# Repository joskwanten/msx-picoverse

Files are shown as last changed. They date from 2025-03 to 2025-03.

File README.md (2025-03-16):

# MSX PicoVerse - The MSX experience driven by the RaspBerry Pi Pico

The MSX PicoVerse is an open-source initiative aimed at developing multi-function cartridges for the MSX line of computers, utilizing variations of the Raspberry Pi Pico development boards with the RP2040 and RP2350 integrated chips. 

This project aspires to enhance the MSX experience by enabling users to load ROMs, connect to wireless networks, or even create new hardware through a software-defined approach.

The project is still in development, and we are looking for contributors to help us develop the hardware and software. If you are interested in contributing, please reach out.

> **Note:** At this moment there is no guarantee that the boards and or software will work as expected. This project is still a work in progress. If you decide to build the hardware, you do so at your own risk.

## Hardware

Hardware was designed in two classes, first covering the RP2040 chip variants and the second covering the RP2350B chip variants. The designs are based on the Raspberry Pico development boards, which are widely available and have a large community of developers.

### PicoVerse 2040 Cartridge

The RP2040 is a dual-core ARM Cortex-M0+ microcontroller operating originally at 133 MHz, featuring 264 KB of SRAM and support for external flash memory. It offers a variety of interfaces, including GPIO pins, SPI, I²C, UART, ADCs, PWM channels, and USB support.

| Prototype PCB (front) | Prototype PCB (back) |
|---|---|
|  |  | 

PicoVerse 2040 cartridges were designed for development boards that expose 30 GPIO pins and are **NOT compatible** with standard Raspberry Pi Pico boards. 

The goal was to use only the GPIO pins available on the boards and avoid the use of IO pin expanders or other components that could increase the complexity (and cost) of the design. 

The PicoVerse 2040 hardware offers almost 16MB to load multiple ROM files into the cartridge flash memory and select which one to boot the MSX. The cartridge has a USB port that can be used to connect it to a PC with Windows or Linux and transfer the ROMs to the Pico flash memory.

A few boards were designed for the PicoVerse 2040 Cartridge. Most of them have the GPIO pins connected to the MSX bus through level shifters. The level shifters are used to convert the 3.3V signals from the Pico board to 5V signals that are used by the MSX bus. 

One of the boards was designed to have the majority of the GPIO pins connected directly to the MSX bus without level shifters. There is a debate about the safety of connecting the Pico GPIOs directly to 5V, as it can damage the board as it is not officially documented that the GPIO pins can be connected directly to 5V. So use the board with the level shifters if you are concerned about that. 

The boards highlighted below have the same features, the only difference is the presence of level shifters in the first one. They both use the [Purple RP2040 board](https://s.click.aliexpress.com/e/_oCiLj5D) that is available on AliExpress and exposes 30 GPIOs.

|Cartridge Design Files|BOM|Image|
|---|---|---|
|[PicoVerse 2040](multirom/hardware/ALIEXPRESS-RP2040-PURPLE/1.0)|[BOM](https://htmlpreview.github.io/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)||
|[PicoVerse 2040 5V](multirom/hardware/ALIEXPRESS-RP2040-PURPLE-5V/1.2)|[BOM](https://htmlpreview.github.io/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)||

### PicoVerse 2350 Cartridge

The RP2350, introduced in August 2024, is a high-performance microcontroller featuring a dual-core, dual-architecture design with selectable Arm Cortex-M33 or Hazard3 RISC-V cores, operating originally at 150 MHz. It includes 520 KB of on-chip SRAM, supports up to 16 MB of external QSPI flash or PSRAM, and offers multiple communication interfaces (2× UART, 2× SPI, 2× I²C), 24 PWM channels, up to 8 ADC channels, 48 GPIO pins, USB 1.1 support, and 12 PIO state machines for flexible interfacing.

| Prototype PCB (front) | Prototype PCB (back) |
|---|---|
|  |  |

PicoVerse 2350 cartridges are based on development boards that expose 48 GPIO pins and are **NOT compatible** with conventional Raspberry Pi Pico 2 development boards, which typically expose only 26 GPIO pins. 

Expanding on the features of the PicoVerse 2040, the PicoVerse 2350 cartridge not only supports loading ROMs into flash memory for execution but also includes a microSD card slot. This allows users to utilize Nextor for loading and saving files to the microSD card.

Additionally, the hardware features an ESP8266 WiFi module for wireless network connectivity and an Adafruit UA-1334 I2C module for audio output.

|Cartridge Design Files|BOM|Image|
|---|---|---|
|TBI|||

## Software

The software for the PicoVerse cartridges is open source. **It is open source but not free software.** 

It is licensed under the [Creative Commons Attribution-NonCommercial-ShareAlike 4.0 International License](http://creativecommons.org/licenses/by-nc-sa/4.0/). You can use the software for personal use, but you cannot use it for commercial purposes. 

You can modify the software and re-publish it, but you must give appropriate credit to the original author and distribute your modifications under the same license. **DO NOT USE THE SOFTWARE FOR COMMERCIAL PURPOSES** without express authorization from the author.

#### PicoVerse 2040 Cartridge Software

As this was the first cartridge to be developed, there are a few software options available. You can check options with descriptions and download links in the [software](2040/software) folder.

The main software for the PicoVerse 2040 cartridge is [MultiRom](2040/software/multirom). This software offers the following features:

|Menu - Page1|Menu - Page2|
|---|---|
|||

* A PC tool to collect all ROM files in the current folder and create a UF2 file that can be used to program the PICO board.
* When the cartridge is inserted into the MSX computer, it offers a menu to select the ROM to boot.
* Support for loading ROMs from the cartridge flash up to 16MB in the following mapper formats:
  * Plain16  
  * Plain32  
  * Linear0  
  * Konami SCC  
  * Konami (without SCC)  
  * ASCII8  
  * ASCII16 
  * NEO-8 
  * NEO-16

More information about the software can be found in the [MultiRom](2040/software/multirom) folder.

#### PicoVerse 2350 Cartridge Software

The software for the PicoVerse 2350 Multirom Cartridge is being developed. You can check options with descriptions and download links in the [software](2350/software) folder.

The main software for the PicoVerse 2350 cartridge is [MultiRom](2350/software/multirom). This software offers the following features:

|Main Menu|Nextor 1|Nextor 2|
|---|---|---|
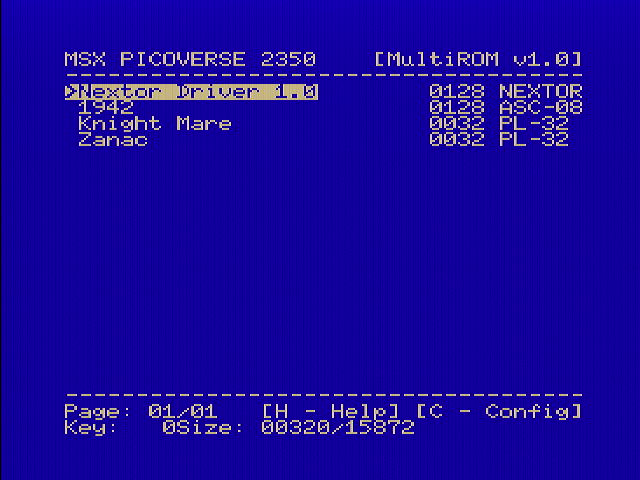
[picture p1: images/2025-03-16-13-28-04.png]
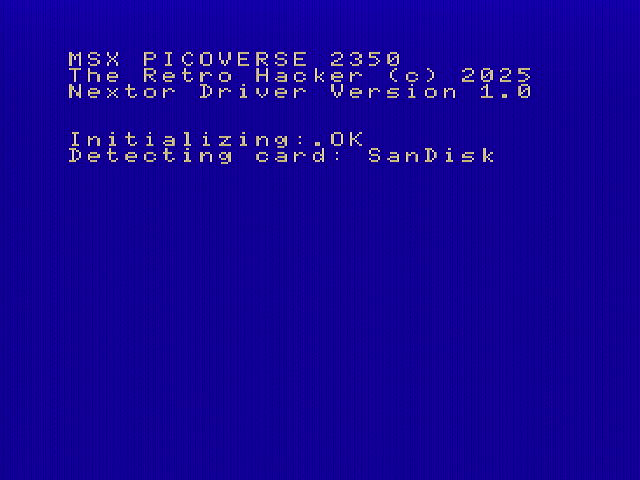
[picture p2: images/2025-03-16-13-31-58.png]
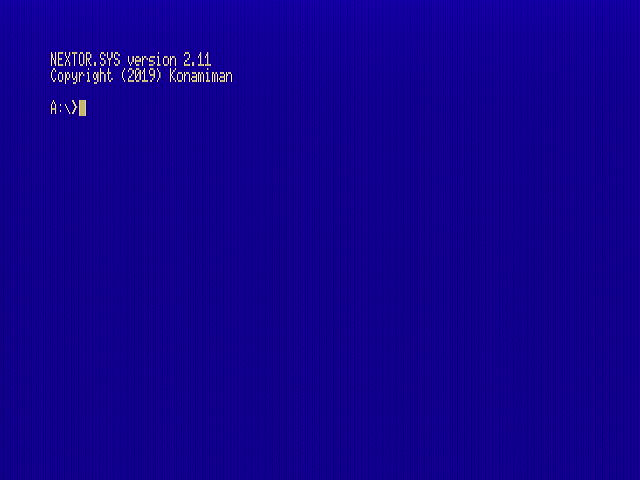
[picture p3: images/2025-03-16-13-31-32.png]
||||

* A PC tool to collect all ROM files in the current folder and create a UF2 file that can be used to program the PICO board.
* When the cartridge is inserted into the MSX computer, it offers a menu to select the ROM to boot.
* Nextor support for loading and saving files to the microSD card. Nextor is the first option available on the menu. You can use that option to run Nextor OS and SofaRun.
* Support for loading MSX ROMs up to 16MB directly from the cartridge flash in the following mapper formats:
  * Plain16  
  * Plain32  
  * Linear0  
  * Konami SCC  
  * Konami (without SCC)  
  * ASCII8  
  * ASCII16 
  * NEO-8 
  * NEO-16

More information about the software can be found in the [MultiRom](2350/software/multirom) folder.

## License 

Open Hardware

This work is licensed under a [Creative Commons Attribution-NonCommercial-ShareAlike 4.0 International License](http://creativecommons.org/licenses/by-nc-sa/4.0/).

* If you remix, transform, or build upon the material, you must distribute your contributions under the same license as the original.
* You may not use the material for commercial purposes.
* You must give appropriate credit, provide a link to the license, and indicate if changes were made. You may do so in any reasonable manner, but not in any way that suggests the licensor endorses you or your use.

**ATTENTION**

This project was made for the retro community and not for commercial purposes. So only retro hardware forums and individual people can build this project.

**THE SALE OF ANY PART OF THIS PROJECT WITHOUT EXPRESS AUTHORIZATION IS PROHIBITED!**

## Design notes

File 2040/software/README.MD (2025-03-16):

# MSX PICOVERSE 2040 SOFTWARE PLAYGROUND

This page summarizes the software options currently available or in development for the PicoVerse 2040 cartridge. 

## Software and Tools you may need to develop for the PicoVerse 2040

* [Visual Studio Code]( https://code.visualstudio.com/) - Code editor that can be used to develop software for the PicoVerse 2040 cartridges.
* [Raspberry Pi Pico SDK](https://github.com/raspberrypi/pico-sdk) - The SDK is a collection of libraries and tools that are designed to make it easy to write programs for the RP2040 microcontroller.  
* [SDCC](http://sdcc.sourceforge.net/) - Small Device C Compiler. Standard C (ANSI C89, ISO C99, ISO C11) compiler that targets the Zilog Z80 based microcontrollers (z80, z180, gbz80, Rabbit 2000/3000, Rabbit 3000A, TLCS-90) for cross-development on Windows, macOS, and Linux. 
* [Fusion-C v1.3](https://github.com/ericb59/FUSION-C-1.3) - Fusion-C is a set of development tools for the MSX system that allows you to write MSX software in C language.
* [MYSYS2](https://www.msys2.org/) - A collection of GNU utilities and open-source software that provides functionality similar to a Linux distribution on Windows. If you are using Windows to develop for the cartridge.
* [GNU Make](https://www.gnu.org/software/make/) - A tool that controls the generation of executables and other non-source files of a program from the program's source files.
* [uf2conv.exe](https://github.com/microsoft/uf2/) - Converts a binary file to a UF2 file. This is used to convert resultant binary files to a UF2 file that can be flashed to the PICO board. 

## Software

### [flashrom](flashrom/)

This is a test program that demonstrates how to use the pico's flash memory as a thumb drive. The program presents the board flash memory as a USB mass storage device. The program can be used to read and write files to the flash memory of the PICO board. 

It is based on the fatfs library, which is a generic FAT file system module for small embedded systems, and SPIFTL library, which is a SPI flash memory driver for the Raspberry Pi Pico. 

### [loadmp3](loadmp3/)

This is a test program that shows how to load an MP3 file from the flash memory of the PICO board and play it using an Adafruit UDA1334 compatible I2S DAC. The PicoVerse 2040 cartridge doesn't have a DAC module as part of the design, but you can use this example to connect an external DAC module and use it to play MP3 files. The program uses the picomp3lib library, which is a small MP3 decoder library for the Raspberry Pi Pico.

### [loadrom](loadrom/)

This is set of software formed by a PC tool and a Pico 2040 firmware that allows to load a single MSX ROM image (up to 16MB) from the flash memory of the PICO board. The MSX ROM image is read directly from the flash memory and then executed. At this moment the tool can load and execute ROMs of the following mapper types:

* Plain16  
* Plain32  
* Linear0  
* Konami SCC  
* Konami (without SCC)  
* ASCII8  
* ASCII16 
* NEO-8 
* NEO-16

To use you need to run the loadrom.exe tool on a PC passing the ROM file as a parameter. The tool will read the ROM file, detect the mapper used using a heuristic approach, and then create a UF2 file that can be used to program the PICO board. 
```
loadrom.exe romfile.rom
```
After the tool execution, you need to connect your cartridge to the PC via the USB-C cable with the BOOTSEL button pushed, and copy the loadrom.uf2 file to drive that will be created in your operating system. The ROM will be loaded and executed on the MSX when the cartridge is inserted to the slot.

### [mmapper](mmapper/)

The mmapper firmwate implements a 128KB memory mapper on the MSX computer. You just need to compile the code and copy the UF2 file to the PICO board. The firmware will be loaded and the memory mapper will be available to the MSX computer.

### [multirom](multirom/)

This is the main software for the PicoVerse 2040 cartridge.

It offers a PC tool (multirom.exe), and a RP2040 firmware that allows the selection of a ROM image from a list of ROMs stored in the flash memory of the PICO board. The ROM image is read directly from the Raspberry Pi Pico flash memory and executed on the MSX. 

|Menu - Page1|Menu - Page2|
|---|---|
|||

At this moment the tool can load and execute following ROM types:

* Plain16  
* Plain32  
* Linear0  
* Konami SCC  
* Konami (without SCC)  
* ASCII8  
* ASCII16  
* NEO-8 
* NEO-16
  
To use it you need to run the multirom.exe tool in the same folder as the ROM files. Please rename the ROM files with names with up to 20 characters in the way you want them to appear in the menu. The tool will read the ROM files, detect their type and create a UF2 file that can be used to program the PICO board. 

```
multirom.exe
```
Then connect your cartridge to the PC via the USB-C cable and copy the multirom.uf2 file to the PICO board. The menu will be executed and you can select the ROM to be loaded to the MSX.

### [musicplayer](musicplayer/)

This is an experimental program that shows a simple MSX music player capable of playing music files in the MP3 format. The program uses the Adafruit UDA1334 compatible I2S DAC to play the music files. The program is based on the loadmp3 example, but it is not fully functional yet.

### [testflash1](testflash1/)

This is small test program that demonstrates how to read the content of a ROM image that is appended to the end of the main program in the PICO flash memory. The ROM data is read from the flash memory and dumped to the serial console in hexdump format.

To use it you need to concatenate the ROM to the resultant bin file for the testflash1. Use the following commands to prepare the UF2 file:

```
copy /b testflash1.bin+romfile.rom testflash1-rom.bin
uf2conv.exe testflash1-rom.bin testflash1-rom.uf2
```

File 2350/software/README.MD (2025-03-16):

# MSX PICOVERSE 2350  SOFTWARE PLAYGROUND

This page summarizes the software options currently available or in development for the PicoVerse 2350 MultiRom cartridge. 

## Software and Tools you may need to develop for the PicoVerse 2350

* [Visual Studio Code]( https://code.visualstudio.com/) - Code editor that can be used to develop software for the PicoVerse 2040 cartridges.
* [Raspberry Pi Pico SDK](https://github.com/raspberrypi/pico-sdk) - The SDK is a collection of libraries and tools that are designed to make it easy to write programs for the RP2040 microcontroller.  
* [SDCC](http://sdcc.sourceforge.net/) - Small Device C Compiler. Standard C (ANSI C89, ISO C99, ISO C11) compiler that targets the Zilog Z80 based microcontrollers (z80, z180, gbz80, Rabbit 2000/3000, Rabbit 3000A, TLCS-90) for cross-development on Windows, macOS, and Linux. 
* [Fusion-C v1.3](https://github.com/ericb59/FUSION-C-1.3) - Fusion-C is a set of development tools for the MSX system that allows you to write MSX software in C language.
* [MYSYS2](https://www.msys2.org/) - A collection of GNU utilities and open-source software that provides functionality similar to a Linux distribution on Windows. If you are using Windows to develop for the cartridge.
* [GNU Make](https://www.gnu.org/software/make/) - A tool that controls the generation of executables and other non-source files of a program from the program's source files.
* [uf2conv.exe](https://github.com/microsoft/uf2/) - Converts a binary file to a UF2 file. This is used to convert resultant binary files to a UF2 file that can be flashed to the PICO board. 

## Software

### [loadrom](loadrom/)

This option offers a tool and correspondent firmware to load a single ROM image from the flash memory of the PICO 2350 board. The ROM image is read directly from the flash memory and then executed. At this moment the tool can load and execute ROMs of the following types:

* Plain16  
* Plain32  
* Linear0  
* Konami SCC  
* Konami (without SCC)  
* ASCII8  
* ASCII16 
* NEO-8 
* NEO-16

To use you need to use a PC to run loadrom.exe passing the ROM file as a parameter. The tool will read the ROM file, detect the mapper used using a heuristic approach, and then create a UF2 file that can be used to program the PICO board. 
```
loadrom.exe romfile.rom
```
After the tool execution, you need to connect your cartridge to the PC via the USB-C cable with the BOOTSEL button pushed, and copy the loadrom.uf2 file to drive that will be created in your operating system. The ROM will be loaded and executed on the MSX when the cartridge is inserted to the slot.

### [multirom](multirom/)

This is the main software for the PicoVerse 2350 cartridge.

|Main Menu|Nextor 1|Nextor 2|
|---|---|---|
||||

This option offers a PC tool (multirom.exe), a firmware that allows the selection of a ROM image from a list of ROMs stored in the flash memory of the PICO 2350 board, the MSX ROM with the menu and the Nextor driver that is compatible with the cartridge. 

At this moment the tool can directly load and execute ROMs of the following mapper types:

* Plain16  
* Plain32  
* Linear0  
* Konami SCC  
* Konami (without SCC)  
* ASCII8  
* ASCII16  
* NEO-8 
* NEO-16

You can also use Nextor to load and save files to the microSD card. The first ROM available in the menu is a Nextor ROM and can be used to load Nextor OS and software directly from the microSD card connected to the cartridge.

To use the software you need to use a PC to run the multirom.exe tool in the same folder as the ROM files. Please rename the ROM files with names with up to 20 characters in the way you want them to appear in the menu. The tool will read the ROM files, detect their type and create a UF2 file that can be used to program the PICO board. The tool also assigns Nextor as the first ROM in the list. 

```
multirom.exe
```
Then connect your cartridge to the PC via the USB-C cable and copy the multirom.uf2 file to the PICO board. The menu will be executed and you can select the ROM to be loaded to the MSX.

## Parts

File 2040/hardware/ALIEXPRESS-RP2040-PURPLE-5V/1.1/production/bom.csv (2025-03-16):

Designator | Footprint | Quantity | Value | LCSC Part #
C1 | 0603 | 1 | 0.1uF
C2 | 0603 | 1 | 10uF
D1 | D_SOD-123 | 1 | 1N5819
EDG1 | msx-con-MSXCART | 1 | MSX_CON
JP1 | SolderJumper-2_P1.3mm_Open_RoundedPad1.0x1.5mm | 1 | Jumper_2_Open
Q1, Q2, Q3, Q4, Q5 | SOT-23 | 5 | BSS138
R1 | 0603 | 1 | 2K
R10, R11, R12, R13, R2, R3, R4, R5, R6, R7, R8, R9 | 0603 | 12 | 10K
U1 | RP2040-PURPLE | 1 | RP2040-PURPLE

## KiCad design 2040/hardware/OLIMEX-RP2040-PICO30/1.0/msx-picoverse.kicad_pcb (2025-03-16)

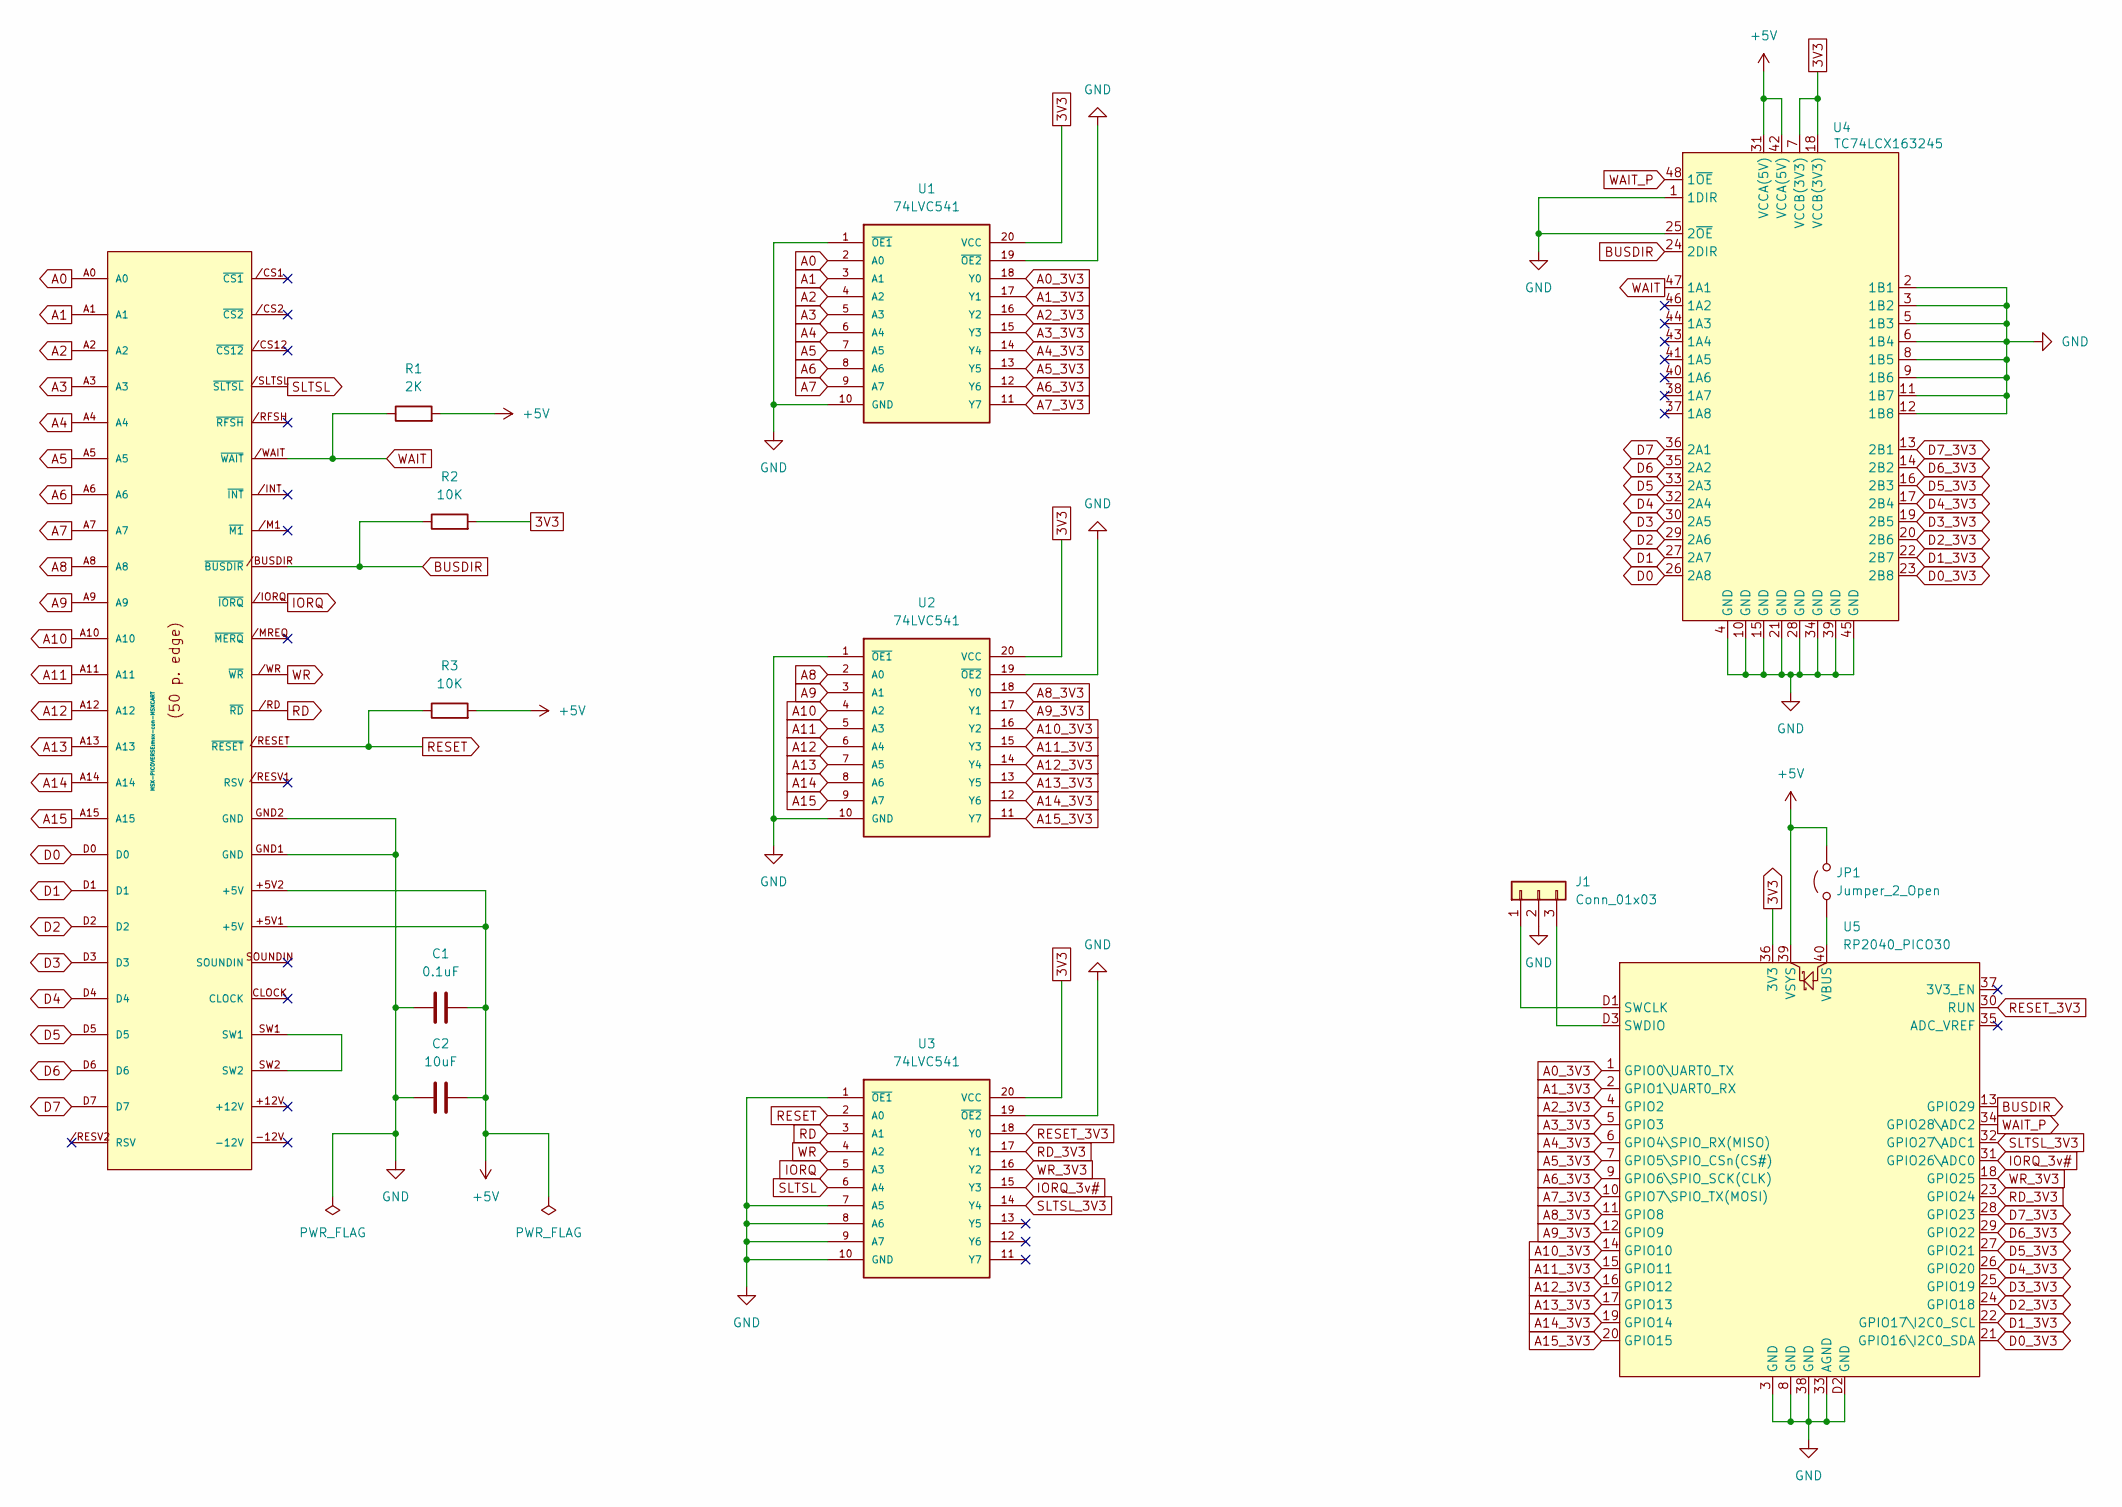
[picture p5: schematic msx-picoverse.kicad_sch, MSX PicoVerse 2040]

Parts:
C1: 0.1uF; C_0603_1608Metric_Pad1.08x0.95mm_HandSolder
C2: 10uF; C_0603_1608Metric_Pad1.08x0.95mm_HandSolder
EDG1: MSX_CON; msx-con-MSXCART
J1: Conn_01x03; PinHeader_1x03_P2.54mm_Vertical
JP1: Jumper_2_Open; SolderJumper-2_P1.3mm_Open_RoundedPad1.0x1.5mm
R1: 2K; R_0603_1608Metric_Pad0.98x0.95mm_HandSolder
R2, R3: 10K; R_0603_1608Metric_Pad0.98x0.95mm_HandSolder
U1, U2, U3: 74LVC541; SOIC127P1032X265-20N; MOUSER_PART_NUMBER 771-LVC541AD112
U4: TC74LCX163245; SSOP-48_7.5x15.9mm_P0.635mm
U5: RP2040_PICO30; RaspberryPi_Pico_Original_SMD_MountingHoles_HandSolder

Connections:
3V3: R2.2, U1.20 (VCC), U2.20 (VCC), U3.20 (VCC), U4.7 (VCCB(3V3)), U4.18 (VCCB(3V3)), U5.36 (3V3)
+5V: C1.2, C2.2, EDG1.+5V1 (+5V), EDG1.+5V2 (+5V), JP1.2 (B), R1.2, R3.2, U4.31 (VCCA(5V)), U4.42 (VCCA(5V)), U5.39 (VSYS)
A0: EDG1.A0, U1.2 (A0)
A0_3V3: U1.18 (Y0), U5.1 (GPIO0\UART0_TX)
A1: EDG1.A1, U1.3 (A1)
A1_3V3: U1.17 (Y1), U5.2 (GPIO1\UART0_RX)
A2: EDG1.A2, U1.4 (A2)
A2_3V3: U1.16 (Y2), U5.4 (GPIO2)
A3: EDG1.A3, U1.5 (A3)
A3_3V3: U1.15 (Y3), U5.5 (GPIO3)
A4: EDG1.A4, U1.6 (A4)
A4_3V3: U1.14 (Y4), U5.6 (GPIO4\SPIO_RX(MISO))
A5: EDG1.A5, U1.7 (A5)
A5_3V3: U1.13 (Y5), U5.7 (GPIO5\SPIO_CSn(CS#))
A6: EDG1.A6, U1.8 (A6)
A6_3V3: U1.12 (Y6), U5.9 (GPIO6\SPIO_SCK(CLK))
A7: EDG1.A7, U1.9 (A7)
A7_3V3: U1.11 (Y7), U5.10 (GPIO7\SPIO_TX(MOSI))
A8: EDG1.A8, U2.2 (A0)
A8_3V3: U2.18 (Y0), U5.11 (GPIO8)
A9: EDG1.A9, U2.3 (A1)
A9_3V3: U2.17 (Y1), U5.12 (GPIO9)
A10: EDG1.A10, U2.4 (A2)
A10_3V3: U2.16 (Y2), U5.14 (GPIO10)
A11: EDG1.A11, U2.5 (A3)
A11_3V3: U2.15 (Y3), U5.15 (GPIO11)
A12: EDG1.A12, U2.6 (A4)
A12_3V3: U2.14 (Y4), U5.16 (GPIO12)
A13: EDG1.A13, U2.7 (A5)
A13_3V3: U2.13 (Y5), U5.17 (GPIO13)
A14: EDG1.A14, U2.8 (A6)
A14_3V3: U2.12 (Y6), U5.19 (GPIO14)
A15: EDG1.A15, U2.9 (A7)
A15_3V3: U2.11 (Y7), U5.20 (GPIO15)
BUSDIR: EDG1./BUSDIR (~BUSDIR), R2.1, U4.24 (2DIR), U5.13 (GPIO29)
D0: EDG1.D0, U4.26 (2A8)
D0_3V3: U4.23 (2B8), U5.21 (GPIO16\I2C0_SDA)
D1: EDG1.D1, U4.27 (2A7)
D1_3V3: U4.22 (2B7), U5.22 (GPIO17\I2C0_SCL)
D2: EDG1.D2, U4.29 (2A6)
D2_3V3: U4.20 (2B6), U5.24 (GPIO18)
D3: EDG1.D3, U4.30 (2A5)
D3_3V3: U4.19 (2B5), U5.25 (GPIO19)
D4: EDG1.D4, U4.32 (2A4)
D4_3V3: U4.17 (2B4), U5.26 (GPIO20)
D5: EDG1.D5, U4.33 (2A3)
D5_3V3: U4.16 (2B3), U5.27 (GPIO21)
D6: EDG1.D6, U4.35 (2A2)
D6_3V3: U4.14 (2B2), U5.29 (GPIO22)
D7: EDG1.D7, U4.36 (2A1)
D7_3V3: U4.13 (2B1), U5.28 (GPIO23)
GND: C1.1, C2.1, EDG1.GND1 (GND), EDG1.GND2 (GND), J1.2, U1.1 (~OE1), U1.10 (GND), U1.19 (~OE2), U2.1 (~OE1), U2.10 (GND), U2.19 (~OE2), U3.1 (~OE1), U3.7 (A5), U3.8 (A6), U3.9 (A7), U3.10 (GND), U3.19 (~OE2), U4.1 (1DIR), U4.2 (1B1), U4.3 (1B2), U4.4 (GND), U4.5 (1B3), U4.6 (1B4), U4.8 (1B5), U4.9 (1B6), U4.10 (GND), U4.11 (1B7), U4.12 (1B8), U4.15 (GND), U4.21 (GND), U4.25 (2~OE), U4.28 (GND), U4.34 (GND), U4.39 (GND), U4.45 (GND), U5.3 (GND), U5.8 (GND), U5.33 (AGND), U5.38 (GND), U5.D2 (GND)
IORQ: EDG1./IORQ (~IORQ), U3.5 (A3)
IORQ_3v#: U3.15 (Y3), U5.31 (GPIO26\ADC0)
unnamed: EDG1.SW1, EDG1.SW2
unnamed: J1.1, U5.D1 (SWCLK)
unnamed: J1.3, U5.D3 (SWDIO)
unnamed: JP1.1 (A), U5.40 (VBUS)
RD: EDG1./RD (~RD), U3.3 (A1)
RD_3V3: U3.17 (Y1), U5.23 (GPIO24)
RESET: EDG1./RESET (~RESET), R3.1, U3.2 (A0)
RESET_3V3: U3.18 (Y0), U5.30 (RUN)
SLTSL: EDG1./SLTSL (~SLTSL), U3.6 (A4)
SLTSL_3V3: U3.14 (Y4), U5.32 (GPIO27\ADC1)
WAIT: EDG1./WAIT (~WAIT), R1.1, U4.47 (1A1)
WAIT_P: U4.48 (1~OE), U5.34 (GPIO28\ADC2)
WR: EDG1./WR (~WR), U3.4 (A2)
WR_3V3: U3.16 (Y2), U5.18 (GPIO25)

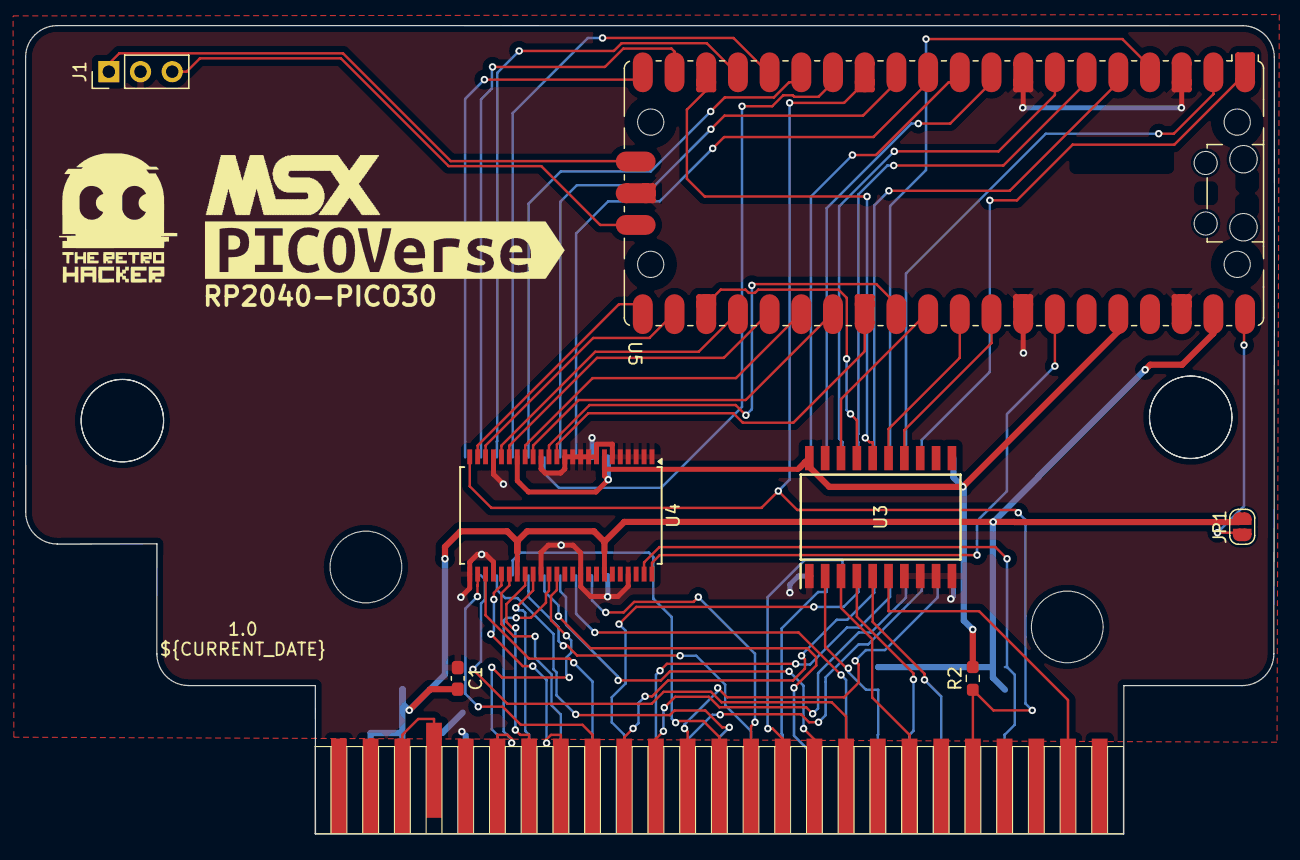
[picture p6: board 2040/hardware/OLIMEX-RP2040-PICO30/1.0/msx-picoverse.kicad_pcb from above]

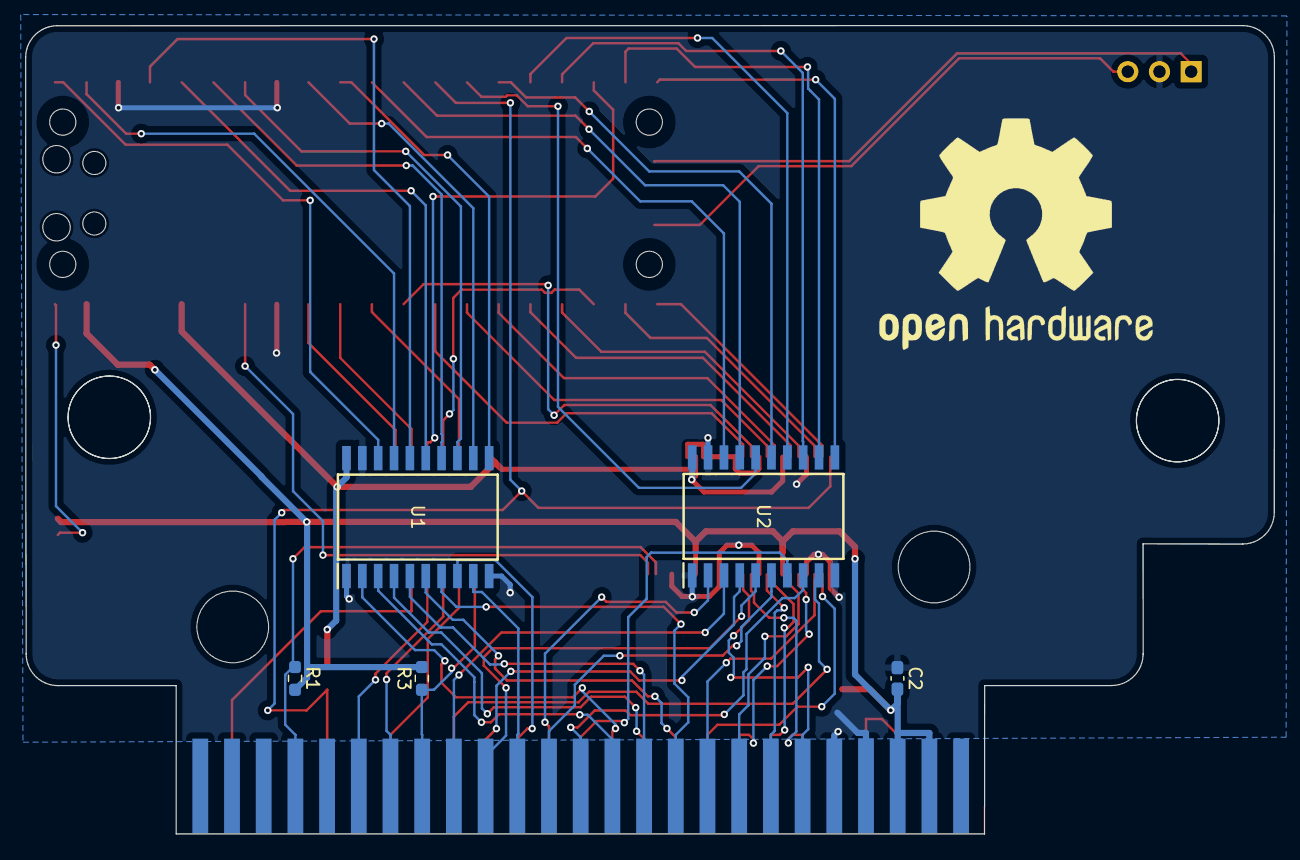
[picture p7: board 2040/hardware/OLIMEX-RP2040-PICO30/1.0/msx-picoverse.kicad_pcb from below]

Board: 2 copper layers, 100.1 x 64.8 mm, 15 parts (5 on the bottom side), 68 nets.

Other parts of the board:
LOGO_MSX: LOGO_MSX
kibuzzard-674F9A42: G***; kibuzzard-674F9A42

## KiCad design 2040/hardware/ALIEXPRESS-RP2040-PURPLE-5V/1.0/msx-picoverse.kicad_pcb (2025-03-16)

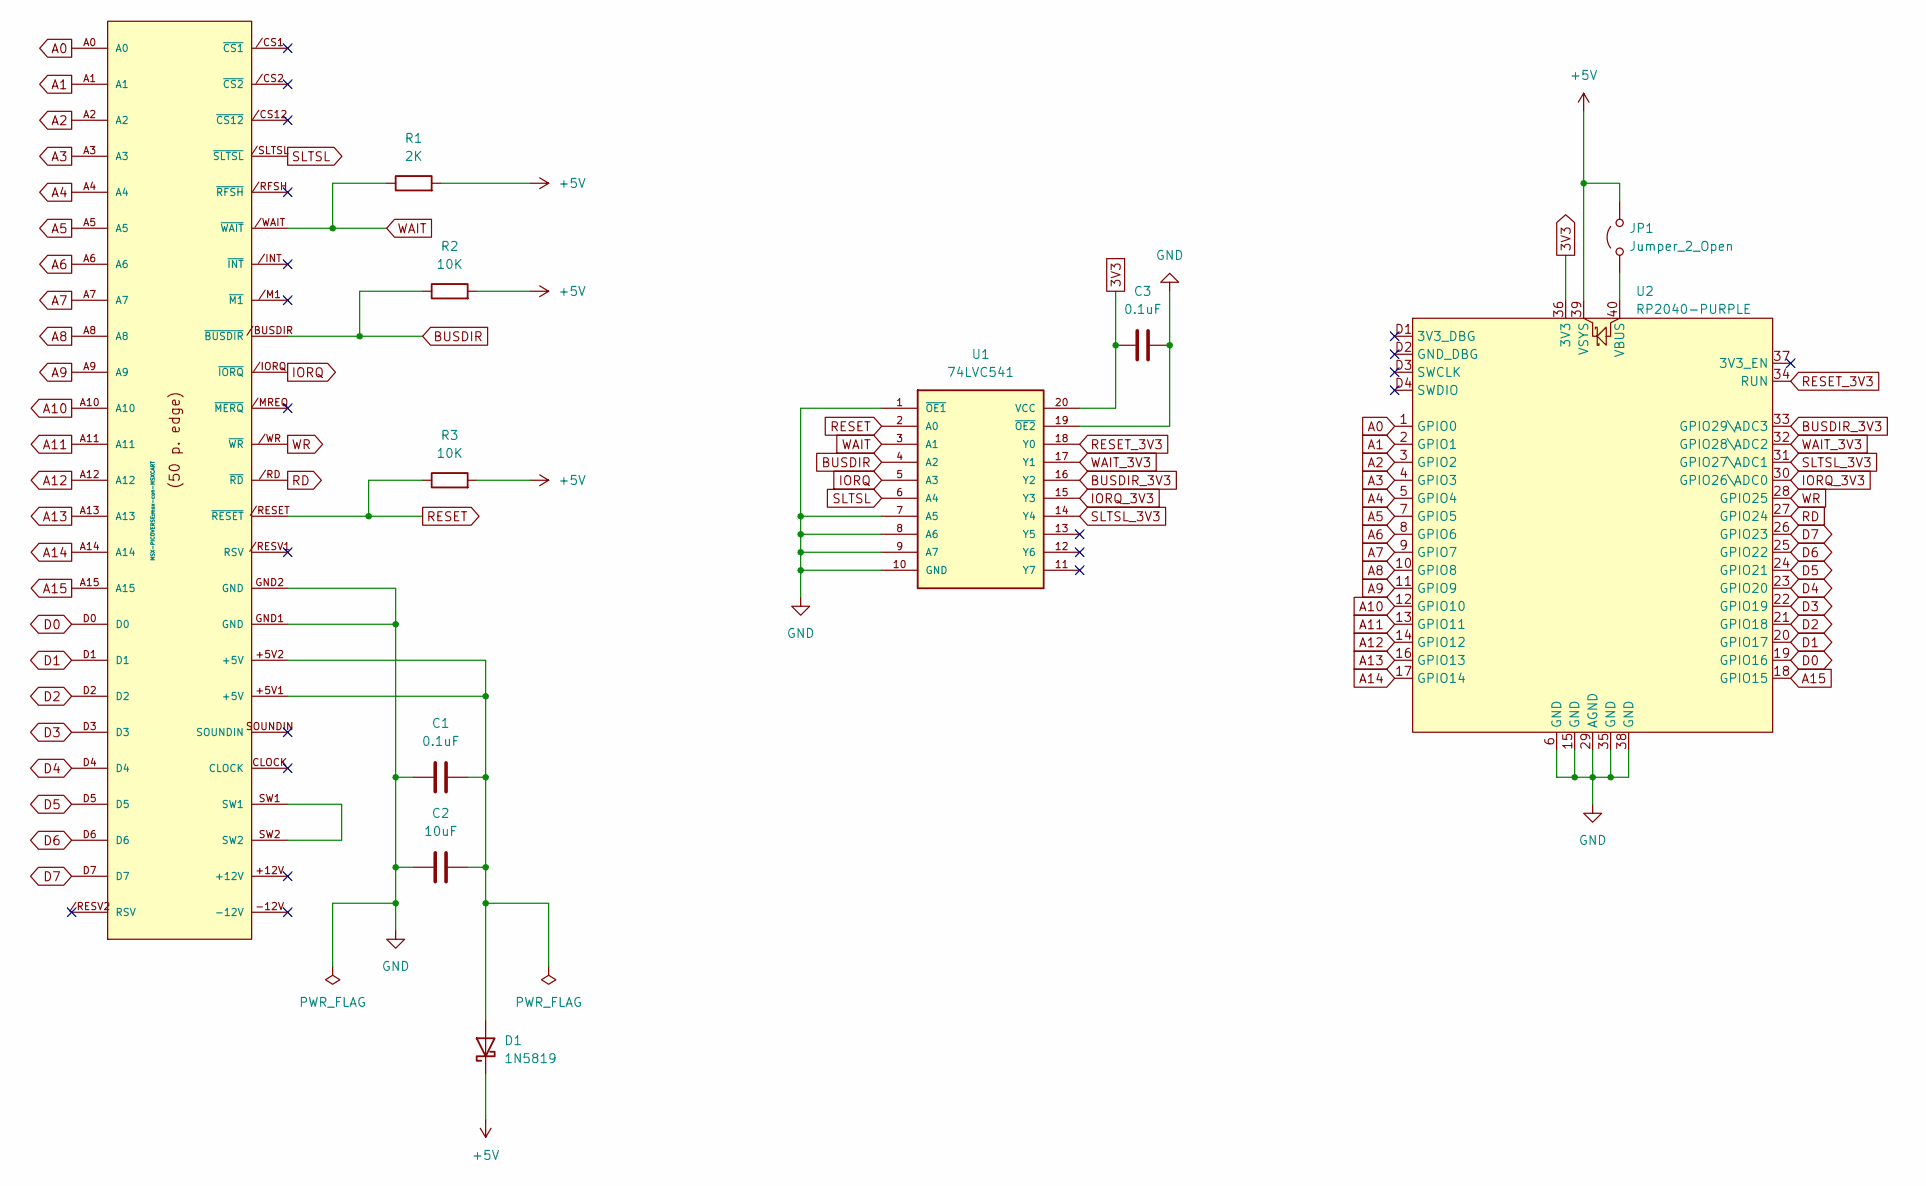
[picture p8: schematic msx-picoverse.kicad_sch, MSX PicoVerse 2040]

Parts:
C1, C3: 0.1uF; C_0603_1608Metric_Pad1.08x0.95mm_HandSolder
C2: 10uF; C_0603_1608Metric_Pad1.08x0.95mm_HandSolder
D1: 1N5819; D_SOD-123
EDG1: MSX_CON; msx-con-MSXCART
JP1: Jumper_2_Open; SolderJumper-2_P1.3mm_Open_RoundedPad1.0x1.5mm
R1: 2K; R_0603_1608Metric_Pad0.98x0.95mm_HandSolder
R2, R3: 10K; R_0603_1608Metric_Pad0.98x0.95mm_HandSolder
U1: 74LVC541; SOIC127P1032X265-20N; MOUSER_PART_NUMBER 771-LVC541AD112
U2: RP2040-PURPLE

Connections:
3V3: C3.1, U1.20 (VCC), U2.36 (3V3)
+5V: D1.1 (K), JP1.2 (B), R1.2, R2.2, R3.2, U2.39 (VSYS)
A0: EDG1.A0, U2.1 (GPIO0)
A1: EDG1.A1, U2.2 (GPIO1)
A2: EDG1.A2, U2.3 (GPIO2)
A3: EDG1.A3, U2.4 (GPIO3)
A4: EDG1.A4, U2.5 (GPIO4)
A5: EDG1.A5, U2.7 (GPIO5)
A6: EDG1.A6, U2.8 (GPIO6)
A7: EDG1.A7, U2.9 (GPIO7)
A8: EDG1.A8, U2.10 (GPIO8)
A9: EDG1.A9, U2.11 (GPIO9)
A10: EDG1.A10, U2.12 (GPIO10)
A11: EDG1.A11, U2.13 (GPIO11)
A12: EDG1.A12, U2.14 (GPIO12)
A13: EDG1.A13, U2.16 (GPIO13)
A14: EDG1.A14, U2.17 (GPIO14)
A15: EDG1.A15, U2.18 (GPIO15)
BUSDIR: EDG1./BUSDIR (~BUSDIR), R2.1, U1.4 (A2)
BUSDIR_3V3: U1.16 (Y2), U2.33 (GPIO29\ADC3)
D0: EDG1.D0, U2.19 (GPIO16)
D1: EDG1.D1, U2.20 (GPIO17)
D2: EDG1.D2, U2.21 (GPIO18)
D3: EDG1.D3, U2.22 (GPIO19)
D4: EDG1.D4, U2.23 (GPIO20)
D5: EDG1.D5, U2.24 (GPIO21)
D6: EDG1.D6, U2.25 (GPIO22)
D7: EDG1.D7, U2.26 (GPIO23)
GND: C1.1, C2.1, C3.2, EDG1.GND1 (GND), EDG1.GND2 (GND), U1.1 (~OE1), U1.7 (A5), U1.8 (A6), U1.9 (A7), U1.10 (GND), U1.19 (~OE2), U2.6 (GND), U2.15 (GND), U2.29 (AGND), U2.35 (GND), U2.38 (GND)
IORQ: EDG1./IORQ (~IORQ), U1.5 (A3)
IORQ_3V3: U1.15 (Y3), U2.30 (GPIO26\ADC0)
unnamed: C1.2, C2.2, D1.2 (A), EDG1.+5V1 (+5V), EDG1.+5V2 (+5V)
unnamed: EDG1.SW1, EDG1.SW2
unnamed: JP1.1 (A), U2.40 (VBUS)
RD: EDG1./RD (~RD), U2.27 (GPIO24)
RESET: EDG1./RESET (~RESET), R3.1, U1.2 (A0)
RESET_3V3: U1.18 (Y0), U2.34 (RUN)
SLTSL: EDG1./SLTSL (~SLTSL), U1.6 (A4)
SLTSL_3V3: U1.14 (Y4), U2.31 (GPIO27\ADC1)
WAIT: EDG1./WAIT (~WAIT), R1.1, U1.3 (A1)
WAIT_3V3: U1.17 (Y1), U2.32 (GPIO28\ADC2)
WR: EDG1./WR (~WR), U2.28 (GPIO25)

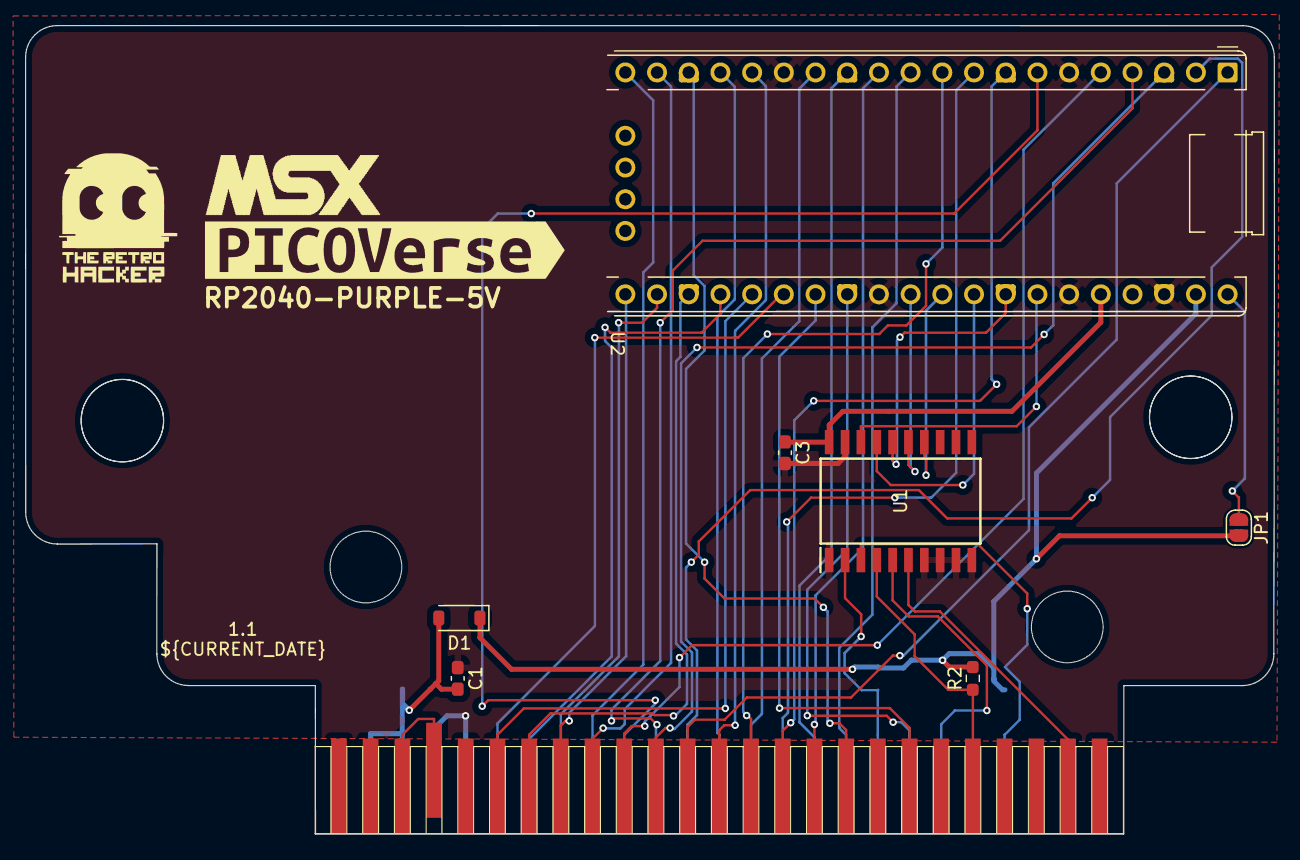
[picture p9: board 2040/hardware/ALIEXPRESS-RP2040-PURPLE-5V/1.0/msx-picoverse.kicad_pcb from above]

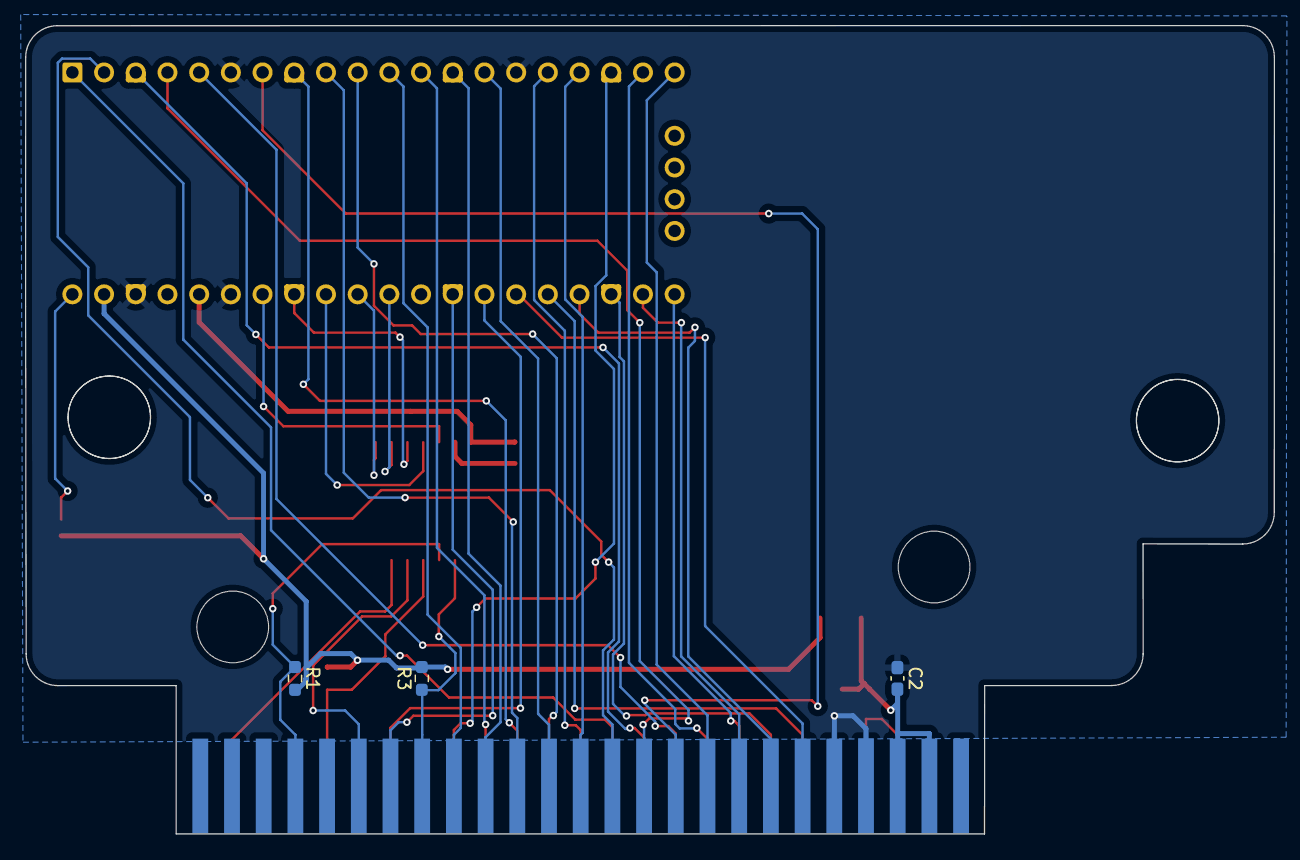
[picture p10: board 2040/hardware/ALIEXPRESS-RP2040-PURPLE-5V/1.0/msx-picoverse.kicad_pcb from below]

Board: 2 copper layers, 100.1 x 64.8 mm, 13 parts (3 on the bottom side), 42 nets.

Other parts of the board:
LOGO_MSX: LOGO_MSX
kibuzzard-674F9A42: G***; kibuzzard-674F9A42

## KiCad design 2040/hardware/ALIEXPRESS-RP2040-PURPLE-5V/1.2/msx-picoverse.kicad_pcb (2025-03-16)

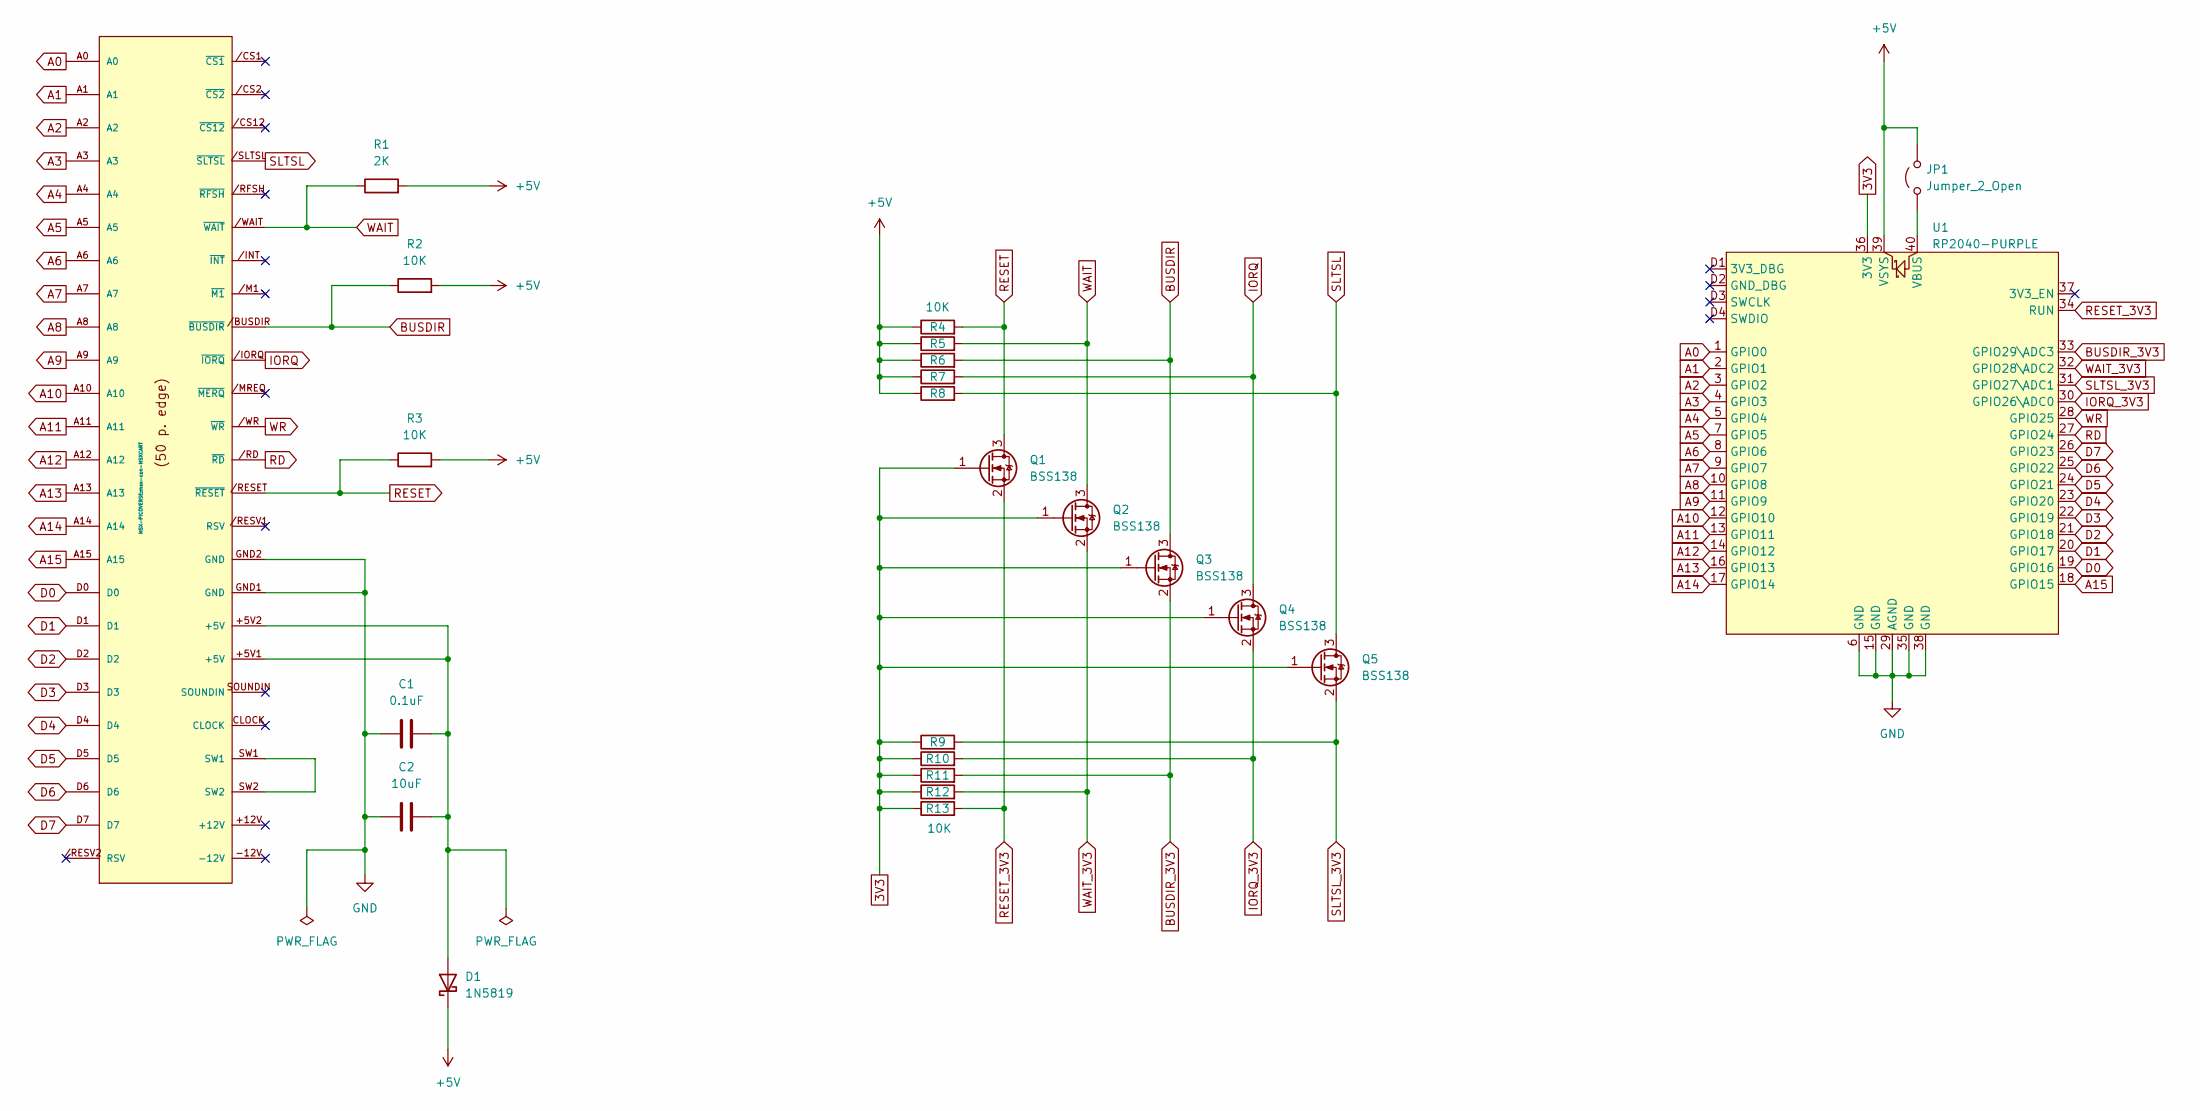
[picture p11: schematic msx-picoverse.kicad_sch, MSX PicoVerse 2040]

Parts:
C1: 0.1uF; C_0603_1608Metric_Pad1.08x0.95mm_HandSolder
C2: 10uF; C_0603_1608Metric_Pad1.08x0.95mm_HandSolder
D1: 1N5819; D_SOD-123
EDG1: MSX_CON; msx-con-MSXCART
JP1: Jumper_2_Open; SolderJumper-2_P1.3mm_Open_RoundedPad1.0x1.5mm
Q1, Q2, Q3, Q4, Q5: BSS138; SOT-23
R1: 2K; R_0603_1608Metric_Pad0.98x0.95mm_HandSolder
R2, R3, R4, R5, R6, R7, R8, R9, R10, R11, R12, R13: 10K; R_0603_1608Metric_Pad0.98x0.95mm_HandSolder
U1: RP2040-PURPLE

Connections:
3V3: Q1.1 (G), Q2.1 (G), Q3.1 (G), Q4.1 (G), Q5.1 (G), R9.1, R10.1, R11.1, R12.1, R13.1, U1.36 (3V3)
+5V: D1.1 (K), JP1.2 (B), R1.2, R2.2, R3.2, R4.1, R5.1, R6.1, R7.1, R8.1, U1.39 (VSYS)
A0: EDG1.A0, U1.1 (GPIO0)
A1: EDG1.A1, U1.2 (GPIO1)
A2: EDG1.A2, U1.3 (GPIO2)
A3: EDG1.A3, U1.4 (GPIO3)
A4: EDG1.A4, U1.5 (GPIO4)
A5: EDG1.A5, U1.7 (GPIO5)
A6: EDG1.A6, U1.8 (GPIO6)
A7: EDG1.A7, U1.9 (GPIO7)
A8: EDG1.A8, U1.10 (GPIO8)
A9: EDG1.A9, U1.11 (GPIO9)
A10: EDG1.A10, U1.12 (GPIO10)
A11: EDG1.A11, U1.13 (GPIO11)
A12: EDG1.A12, U1.14 (GPIO12)
A13: EDG1.A13, U1.16 (GPIO13)
A14: EDG1.A14, U1.17 (GPIO14)
A15: EDG1.A15, U1.18 (GPIO15)
BUSDIR: EDG1./BUSDIR (~BUSDIR), Q3.3 (D), R2.1, R6.2
BUSDIR_3V3: Q3.2 (S), R11.2, U1.33 (GPIO29\ADC3)
D0: EDG1.D0, U1.19 (GPIO16)
D1: EDG1.D1, U1.20 (GPIO17)
D2: EDG1.D2, U1.21 (GPIO18)
D3: EDG1.D3, U1.22 (GPIO19)
D4: EDG1.D4, U1.23 (GPIO20)
D5: EDG1.D5, U1.24 (GPIO21)
D6: EDG1.D6, U1.25 (GPIO22)
D7: EDG1.D7, U1.26 (GPIO23)
GND: C1.1, C2.1, EDG1.GND1 (GND), EDG1.GND2 (GND), U1.6 (GND), U1.15 (GND), U1.29 (AGND), U1.35 (GND), U1.38 (GND)
IORQ: EDG1./IORQ (~IORQ), Q4.3 (D), R7.2
IORQ_3V3: Q4.2 (S), R10.2, U1.30 (GPIO26\ADC0)
unnamed: C1.2, C2.2, D1.2 (A), EDG1.+5V1 (+5V), EDG1.+5V2 (+5V)
unnamed: EDG1.SW1, EDG1.SW2
unnamed: JP1.1 (A), U1.40 (VBUS)
RD: EDG1./RD (~RD), U1.27 (GPIO24)
RESET: EDG1./RESET (~RESET), Q1.3 (D), R3.1, R4.2
RESET_3V3: Q1.2 (S), R13.2, U1.34 (RUN)
SLTSL: EDG1./SLTSL (~SLTSL), Q5.3 (D), R8.2
SLTSL_3V3: Q5.2 (S), R9.2, U1.31 (GPIO27\ADC1)
WAIT: EDG1./WAIT (~WAIT), Q2.3 (D), R1.1, R5.2
WAIT_3V3: Q2.2 (S), R12.2, U1.32 (GPIO28\ADC2)
WR: EDG1./WR (~WR), U1.28 (GPIO25)

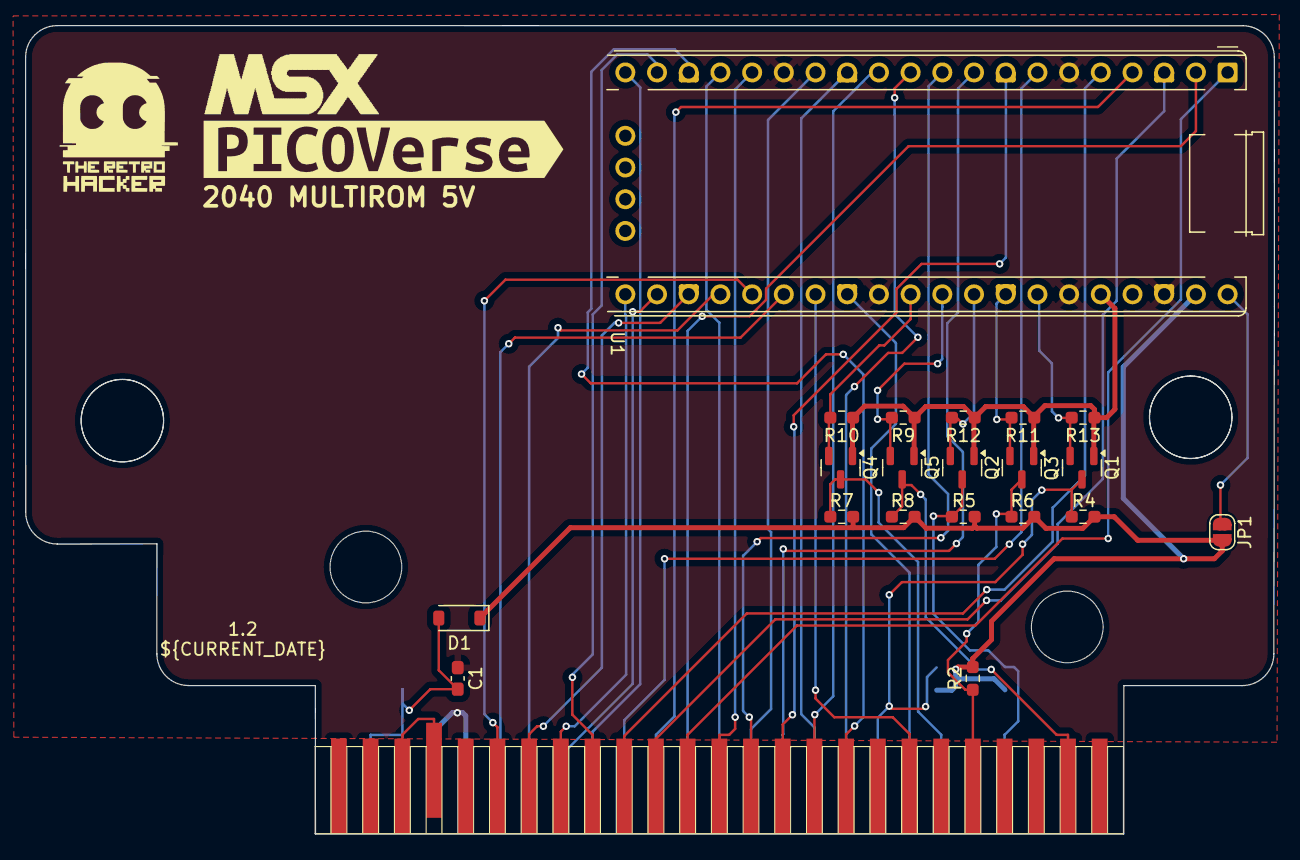
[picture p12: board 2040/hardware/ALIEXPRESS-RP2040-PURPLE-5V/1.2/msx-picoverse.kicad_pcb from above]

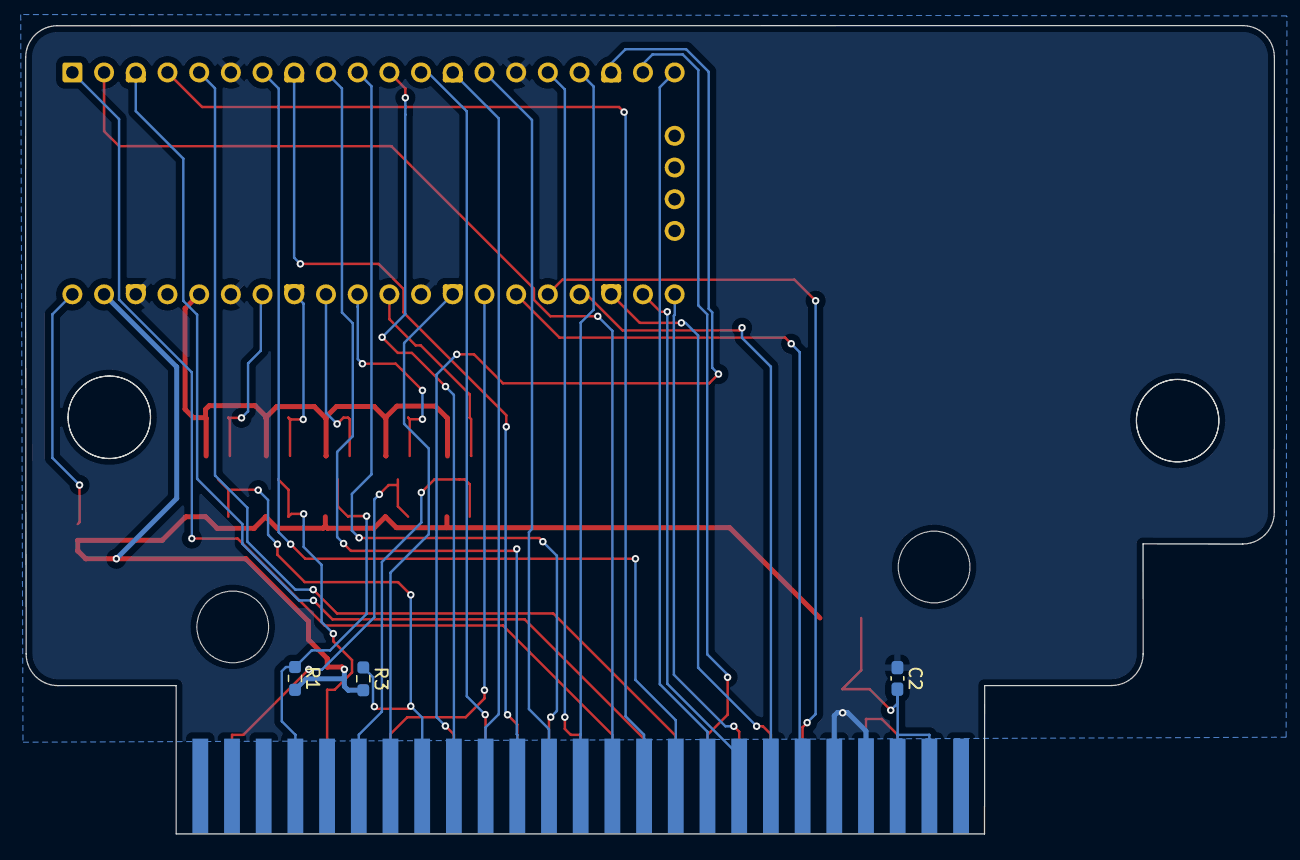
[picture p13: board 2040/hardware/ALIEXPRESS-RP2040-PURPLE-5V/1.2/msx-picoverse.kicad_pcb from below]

Board: 2 copper layers, 100.1 x 64.8 mm, 26 parts (3 on the bottom side), 42 nets.

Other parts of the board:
LOGO_MSX: LOGO_MSX
kibuzzard-674F9A42: G***; kibuzzard-674F9A42

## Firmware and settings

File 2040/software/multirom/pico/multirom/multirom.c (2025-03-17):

// MSX PICOVERSE PROJECT
// (c) 2024 Cristiano Goncalves
// The Retro Hacker
//
// multirom.c - This is the Raspberry Pico firmware that will be used to load ROMs into the MSX
//
// This firmware is responsible for loading the multirom menu and the ROMs selected by the user into the MSX. When flashed through the 
// multirom tool, it will be stored on the pico flash memory followed by the MSX MENU ROM (with the config) and all the ROMs processed by the 
// multirom tool. The sofware in this firmware will load the first 32KB ROM that contains the menu into the MSX and it will allow the user
// to select a ROM to be loaded into the MSX. The selected ROM will be loaded into the MSX and the MSX will be reseted to run the selected ROM.
//
// This work is licensed  under a "Creative Commons Attribution-NonCommercial-ShareAlike 4.0 International
// License". https://creativecommons.org/licenses/by-nc-sa/4.0/

#include <stdio.h>
#include <string.h>
#include "pico/stdlib.h"
#include "pico/multicore.h"
#include "hardware/clocks.h"
#include "multirom.h"
#include "wireless.h"

// config area and buffer for the ROM data
#define MONITOR_ADDR    0x9D01     // Monitor ROM address - Configuration binary 0x8000+(ROM_RECORD_SIZE*MAX_ROM_RECORDS)+1 = 0x8000 +0x1D00 + 0x1 = 0x9D01
#define ROM_RECORD_SIZE 29      // Size of the ROM record in the configuration area in bytes
#define MAX_ROM_RECORDS 256     // Maximum ROM files supported 2^8=256
#define ROM_NAME_MAX    20         // Maximum size of the ROM name

// This symbol marks the end of the main program in flash.
// Custom data starts right after it
extern unsigned char __flash_binary_end;

//pointer to the custom data
const uint8_t *rom = (const uint8_t *)&__flash_binary_end;

// Structure to represent a ROM record
// The ROM record will contain the name of the ROM, the mapper code, the size of the ROM and the offset in the flash memory
// Name: ROM_NAME_MAX bytes
// Mapper: 1 byte
// Size: 4 bytes
// Offset: 4 bytes
typedef struct {
    char Name[ROM_NAME_MAX];
    unsigned char Mapper;
    unsigned long Size;
    unsigned long Offset;
} ROMRecord;

ROMRecord records[MAX_ROM_RECORDS]; // Array to store the ROM records

// Initialize GPIO pins
static inline void setup_gpio()
{
    // address pins
    gpio_init(PIN_A0);  gpio_set_dir(PIN_A0, GPIO_IN);
    gpio_init(PIN_A1);  gpio_set_dir(PIN_A1, GPIO_IN);
    gpio_init(PIN_A2);  gpio_set_dir(PIN_A2, GPIO_IN);
    gpio_init(PIN_A3);  gpio_set_dir(PIN_A3, GPIO_IN);
    gpio_init(PIN_A4);  gpio_set_dir(PIN_A4, GPIO_IN);
    gpio_init(PIN_A5);  gpio_set_dir(PIN_A5, GPIO_IN);
    gpio_init(PIN_A6);  gpio_set_dir(PIN_A6, GPIO_IN);
    gpio_init(PIN_A7);  gpio_set_dir(PIN_A7, GPIO_IN);
    gpio_init(PIN_A8);  gpio_set_dir(PIN_A8, GPIO_IN);
    gpio_init(PIN_A9);  gpio_set_dir(PIN_A9, GPIO_IN);
    gpio_init(PIN_A10); gpio_set_dir(PIN_A10, GPIO_IN);
    gpio_init(PIN_A11); gpio_set_dir(PIN_A11, GPIO_IN);
    gpio_init(PIN_A12); gpio_set_dir(PIN_A12, GPIO_IN);
    gpio_init(PIN_A13); gpio_set_dir(PIN_A13, GPIO_IN);
    gpio_init(PIN_A14); gpio_set_dir(PIN_A14, GPIO_IN);
    gpio_init(PIN_A15); gpio_set_dir(PIN_A15, GPIO_IN);

    // data pins
    gpio_init(PIN_D0); 
    gpio_init(PIN_D1); 
    gpio_init(PIN_D2); 
    gpio_init(PIN_D3); 
    gpio_init(PIN_D4); 
    gpio_init(PIN_D5); 
    gpio_init(PIN_D6);  
    gpio_init(PIN_D7); 

    // Initialize control pins as input
    gpio_init(PIN_RD); gpio_set_dir(PIN_RD, GPIO_IN);
    gpio_init(PIN_WR); gpio_set_dir(PIN_WR, GPIO_IN);
    gpio_init(PIN_IORQ); gpio_set_dir(PIN_IORQ, GPIO_IN);
    gpio_init(PIN_SLTSL); gpio_set_dir(PIN_SLTSL, GPIO_IN);
}

// read_ulong - Read a 4-byte value from the memory area
// This function will read a 4-byte value from the memory area pointed by ptr and return the value as an unsigned long
// Parameters:
//   ptr - Pointer to the memory area to read the value from
// Returns:
//   The 4-byte value as an unsigned long 
unsigned long read_ulong(const unsigned char *ptr) {
    return (unsigned long)ptr[0] |
           ((unsigned long)ptr[1] << 8) |
           ((unsigned long)ptr[2] << 16) |
           ((unsigned long)ptr[3] << 24);
}

// isEndOfData - Check if the memory area is the end of the data
// This function will check if the memory area pointed by memory is the end of the data. The end of the data is defined by all bytes being 0xFF.
// Parameters:
//   memory - Pointer to the memory area to check
// Returns:
//   1 if the memory area is the end of the data, 0 otherwise
int isEndOfData(const unsigned char *memory) {
    for (int i = 0; i < ROM_RECORD_SIZE; i++) {
        if (memory[i] != 0xFF) {
            return 0;
        }
    }
    return 1;
}

//load the MSX Menu ROM into the MSX
int __no_inline_not_in_flash_func(loadrom_msx_menu)(uint32_t offset)
{
    int record_count = 0; // Record count
    const uint8_t *record_ptr = rom + offset + 0x4000; // Pointer to the ROM records
    for (int i = 0; i < MAX_ROM_RECORDS; i++)      // Read the ROMs from the configuration area
    {
        if (isEndOfData(record_ptr)) {
            break; // Stop if end of data is reached
        }
        memcpy(records[record_count].Name, record_ptr, ROM_NAME_MAX); // Copy the ROM name
        record_ptr += ROM_NAME_MAX; // Move the pointer to the next field
        records[record_count].Mapper = *record_ptr++; // Read the mapper code
        records[record_count].Size = read_ulong(record_ptr); // Read the ROM size
        record_ptr += sizeof(unsigned long); // Move the pointer to the next field
        records[record_count].Offset = read_ulong(record_ptr); // Read the ROM offset
        record_ptr += sizeof(unsigned long); // Move the pointer to the next record
        record_count++; // Increment the record count
    }

    uint8_t rom_index = 0;
    gpio_set_dir_in_masked(0xFF << 16); // Set data bus to input mode
    bool rom_selected = false; // ROM selected flag
    while (true)  // Loop until a ROM is selected
    {
        // Check control signals
        bool sltsl = !(gpio_get(PIN_SLTSL)); // Slot selected (active low)
        bool rd = !(gpio_get(PIN_RD));       // Read cycle (active low)
        bool wr = !(gpio_get(PIN_WR));       // Write cycle (active low, not used)
        
        uint16_t addr = gpio_get_all() & 0x00FFFF; // Read the address bus
        if (sltsl) 
        {
            if (addr >= 0x4000 && addr <= 0xBFFF) // Check if the address is within the ROM range
            {
                if (rd)
                {
                    gpio_set_dir_out_masked(0xFF << 16); // Set data bus to output mode
                    uint32_t rom_addr = offset + (addr - 0x4000); // Calculate flash address
                    gpio_put_masked(0xFF0000, rom[rom_addr] << 16); // Write the data to the data bus
                    while (!(gpio_get(PIN_RD))) { // Wait until the read cycle completes (RD goes high)
                        tight_loop_contents();
                    }
                    gpio_set_dir_in_masked(0xFF << 16); // Set data bus to input mode
                }
                if (wr && addr == 0x9D01) // Monitor ROM address 0x9D01
                {   
                    rom_index = (gpio_get_all() >> 16) & 0xFF;
                    while (!(gpio_get(PIN_WR))) { // Wait until the write cycle completes (WR goes high){
                        tight_loop_contents();
                    }
                    gpio_set_dir_in_masked(0xFF << 16); // Set data bus to input mode
                    rom_selected = true;    // ROM selected
                }
            } 
        }
        if (rd && addr == 0x0000 && rom_selected)   // lets return the rom_index and load the selected ROM
        {
            return rom_index;
        }
    }
}

// loadrom_plain32 - Load a simple 32KB (or less) ROM into the MSX directly from the pico flash
// 32KB ROMS have two pages of 16Kb each in the following areas:
// 0x4000-0x7FFF and 0x8000-0xBFFF
// AB is on 0x0000, 0x0001
// 16KB ROMS have only one page in the 0x4000-0x7FFF area
// AB is on 0x0000, 0x0001
void __no_inline_not_in_flash_func(loadrom_plain32)(uint32_t offset)
{
    gpio_set_dir_in_masked(0xFF << 16); // Set data bus to input mode
    while (true) 
    {
        bool sltsl = !(gpio_get(PIN_SLTSL)); // Slot selected (active low)
        bool rd = !(gpio_get(PIN_RD));       // Read cycle (active low)

        if (sltsl) 
        {
            uint16_t addr = gpio_get_all() & 0x00FFFF; // Read the address bus
            if (addr >= 0x4000 && addr <= 0xBFFF) // Check if the address is within the ROM range
            {
                if (rd) // Handle read requests within the ROM address range
                {
                    uint32_t rom_addr = offset + (addr - 0x4000); // Calculate flash address
                    gpio_set_dir_out_masked(0xFF << 16); // Set data bus to output mode
                    gpio_put_masked(0xFF0000, rom[rom_addr] << 16); // Write the data to the data bus
                    while (!(gpio_get(PIN_RD)))  // Wait until the read cycle completes (RD goes high)
                    {
                        tight_loop_contents();
                    }
                    gpio_set_dir_in_masked(0xFF << 16); // Return data bus to input mode after cycle completes
                }
            } 
        } 
    }
}

// loadrom_linear48 - Load a simple 48KB Linear0 ROM into the MSX directly from the pico flash
// Those ROMs have three pages of 16Kb each in the following areas:
// 0x0000-0x3FFF, 0x4000-0x7FFF and 0x8000-0xBFFF
// AB is on 0x4000, 0x4001
void __no_inline_not_in_flash_func(loadrom_linear48)(uint32_t offset)
{
    gpio_set_dir_in_masked(0xFF << 16); // Set data bus to input mode
    while (true) 
    {
        // Check control signals
        bool sltsl = !(gpio_get(PIN_SLTSL)); // Slot selected (active low)
        bool rd = !(gpio_get(PIN_RD));       // Read cycle (active low)

        if (sltsl)
        {
            uint16_t addr = gpio_get_all() & 0x00FFFF; // Read the address bus
            if (addr >= 0x0000 && addr <= 0xBFFF) // Check if the address is within the ROM range
            {
                if (rd)
                {
                    uint32_t rom_addr = offset + addr; // Calculate flash address
                    gpio_set_dir_out_masked(0xFF << 16); // Set data bus to output mode
                    gpio_put_masked(0xFF0000, rom[rom_addr] << 16); // Write the data to the data bus
                    while (gpio_get(PIN_RD) == 0) // Wait until the read cycle completes (RD goes high)
                    {
                        tight_loop_contents();
                    }
                    gpio_set_dir_in_masked(0xFF << 16); // Set data bus to input mode
                }
            }
        }
    }
}

// loadrom_konamiscc - Load a any Konami SCC ROM into the MSX directly from the pico flash
// The KonamiSCC ROMs are divided into 8KB segments, managed by a memory mapper that allows dynamic switching of these segments 
// into the MSX's address space. Since the size of the mapper is 8Kb, the memory banks are:
// Bank 1: 4000h - 5FFFh , Bank 2: 6000h - 7FFFh, Bank 3: 8000h - 9FFFh, Bank 4: A000h - BFFFh
// And the address to change banks are:
// Bank 1: 5000h - 57FFh (5000h used), Bank 2: 7000h - 77FFh (7000h used), Bank 3: 9000h - 97FFh (9000h used), Bank 4: B000h - B7FFh (B000h used)
// AB is on 0x0000, 0x0001
void __no_inline_not_in_flash_func(loadrom_konamiscc)(uint32_t offset)
{
    uint8_t bank_registers[4] = {0, 1, 2, 3}; // Initial banks 0-3 mapped

    gpio_set_dir_in_masked(0xFF << 16); // Set data bus to input mode
    while (true) 
    {
        // Check control signals
        bool sltsl = !(gpio_get(PIN_SLTSL)); // Slot selected (active low)
        bool rd = !(gpio_get(PIN_RD));       // Read cycle (active low)
        bool wr = !(gpio_get(PIN_WR));       // Write cycle (active low)

        if (sltsl)
        {
            uint16_t addr = gpio_get_all() & 0x00FFFF; // Read the address bus
            if (addr >= 0x4000 && addr <= 0xBFFF)  // Check if the address is within the ROM range
            {
                if (rd) 
                {
                    gpio_set_dir_out_masked(0xFF << 16); // Set data bus to output mode
                    uint32_t rom_offset = offset + (bank_registers[(addr - 0x4000) >> 13] * 0x2000) + (addr & 0x1FFF); // Calculate the ROM offset
                    gpio_put_masked(0xFF0000, rom[rom_offset] << 16); // Write the data to the data bus
                    while (!(gpio_get(PIN_RD)))  // Wait until the read cycle completes (RD goes high)
                    {
                        tight_loop_contents();
                    }
                    gpio_set_dir_in_masked(0xFF << 16); // Return data bus to input mode after cycle completes
                } else if (wr) 
                {
                    // Handle writes to bank switching addresses
                    if ((addr >= 0x5000)  && (addr <= 0x57FF)) { 
                        bank_registers[0] = (gpio_get_all() >> 16) & 0xFF; // Read the data bus and store in bank register
                    } else if ((addr >= 0x7000) && (addr <= 0x77FF)) {
                        bank_registers[1] = (gpio_get_all() >> 16) & 0xFF;
                    } else if ((addr >= 0x9000) && (addr <= 0x97FF)) {
                        bank_registers[2] = (gpio_get_all() >> 16) & 0xFF;
                    } else if ((addr >= 0xB000) && (addr <= 0xB7FF)) {
                        bank_registers[3] = (gpio_get_all() >> 16) & 0xFF;
                    }

                    while (!(gpio_get(PIN_WR)))
                    {
                        tight_loop_contents();
                    }
                }
            }
        }
    }
}

// loadrom_konami - Load a Konami (without SCC) ROM into the MSX directly from the pico flash
// The Konami (without SCC) ROM is divided into 8KB segments, managed by a memory mapper that allows dynamic switching of these segments into the MSX's address space
// Since the size of the mapper is 8Kb, the memory banks are:
//  Bank 1: 4000h - 5FFFh, Bank 2: 6000h - 7FFFh, Bank 3: 8000h - 9FFFh, Bank 4: A000h - BFFFh
// And the addresses to change banks are:
//	Bank 1: <none>, Bank 2: 6000h - 67FFh (6000h used), Bank 3: 8000h - 87FFh (8000h used), Bank 4: A000h - A7FFh (A000h used)
// AB is on 0x0000, 0x0001
void __no_inline_not_in_flash_func(loadrom_konami)(uint32_t offset)
{
    uint8_t bank_registers[4] = {0, 1, 2, 3}; // Initial banks 0-3 mapped

    gpio_set_dir_in_masked(0xFF << 16);
    while (true) 
    {
        // Check control signals
        bool sltsl = !(gpio_get(PIN_SLTSL)); // Slot selected (active low)
        bool rd = !(gpio_get(PIN_RD));       // Read cycle (active low)
        bool wr = !(gpio_get(PIN_WR));       // Write cycle (active low)

        if (sltsl)
        {
            uint16_t addr = gpio_get_all() & 0x00FFFF; // Read the address bus
            if (addr >= 0x4000 && addr <= 0xBFFF) 
            {
                if (rd) 
                {
                    gpio_set_dir_out_masked(0xFF << 16);
                    uint32_t rom_offset = offset + (bank_registers[(addr - 0x4000) >> 13] * 0x2000) + (addr & 0x1FFF); // Calculate the ROM offset
                    gpio_put_masked(0xFF0000, rom[rom_offset] << 16);
                    while (!(gpio_get(PIN_RD))) 
                    {
                        tight_loop_contents();
                    }
                    gpio_set_dir_in_masked(0xFF << 16);

                }else if (wr) {
                    // Handle writes to bank switching addresses
                    if ((addr >= 0x6000) && (addr <= 0x67FF)) {
                        bank_registers[1] = (gpio_get_all() >> 16) & 0xFF;
                    } else if ((addr >= 0x8000) && (addr <= 0x87FF)) {
                        bank_registers[2] = (gpio_get_all() >> 16) & 0xFF;
                    } else if ((addr >= 0xA000) && (addr <= 0xA7FF)) {
                        bank_registers[3] = (gpio_get_all() >> 16) & 0xFF;
                    }

                    while (!(gpio_get(PIN_WR))) 
                    {
                        tight_loop_contents();
                    }
                }
            }
        }
    }
}

// loadrom_ascii8 - Load an ASCII8 ROM into the MSX directly from the pico flash
// The ASCII8 ROM is divided into 8KB segments, managed by a memory mapper that allows dynamic switching of these segments into the MSX's address space
// Since the size of the mapper is 8Kb, the memory banks are:
// Bank 1: 4000h - 5FFFh , Bank 2: 6000h - 7FFFh, Bank 3: 8000h - 9FFFh, Bank 4: A000h - BFFFh
// And the address to change banks are:
// Bank 1: 6000h - 67FFh (6000h used), Bank 2: 6800h - 6FFFh (6800h used), Bank 3: 7000h - 77FFh (7000h used), Bank 4: 7800h - 7FFFh (7800h used)
// AB is on 0x0000, 0x0001
void __no_inline_not_in_flash_func(loadrom_ascii8)(uint32_t offset)
{

    uint8_t bank_registers[4] = {0, 1, 2, 3}; // Initial banks 0-3 mapped

    gpio_set_dir_in_masked(0xFF << 16);
    while (true) 
    {
        bool sltsl = !(gpio_get(PIN_SLTSL)); // Slot selected (active low)
        bool rd = !(gpio_get(PIN_RD));       // Read cycle (active low)
        bool wr = !(gpio_get(PIN_WR));       // Write cycle (active low)

        if (sltsl) {
            uint16_t addr = gpio_get_all() & 0x00FFFF; // Read the address bus
            if (addr >= 0x4000 && addr <= 0xBFFF) 
            {
                if (rd) 
                {
                    gpio_set_dir_out_masked(0xFF << 16); // Set data bus to output mode
                    uint32_t rom_offset = offset + (bank_registers[(addr - 0x4000) >> 13] * 0x2000) + (addr & 0x1FFF); // Calculate the ROM offset
                    gpio_put_masked(0xFF0000, rom[rom_offset] << 16); // Write the data to the data bus
                    while (!(gpio_get(PIN_RD)))  { // Wait for the read cycle to complete
                        tight_loop_contents();
                    }
                    gpio_set_dir_in_masked(0xFF << 16); // Return data bus to input mode after the read cycle
                } else if (wr)  // Handle writes to bank switching addresses
                { 
                    if ((addr >= 0x6000) && (addr <= 0x67FF)) { 
                        bank_registers[0] = (gpio_get_all() >> 16) & 0xFF; // Read the data bus and store in bank register
                    } else if ((addr >= 0x6800) && (addr <= 0x6FFF)) {
                        bank_registers[1] = (gpio_get_all() >> 16) & 0xFF;
                    } else if ((addr >= 0x7000) && (addr <= 0x77FF)) {
                        bank_registers[2] = (gpio_get_all() >> 16) & 0xFF;
                    } else if ((addr >= 0x7800) && (addr <= 0x7FFF)) {
                        bank_registers[3] = (gpio_get_all() >> 16) & 0xFF;
                    }

                    while (!(gpio_get(PIN_WR))) 
                    {
                        tight_loop_contents();
                    }
                }
            }
        }
    }
}
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
int main()
{
    set_sys_clock_khz(270000, true);     // Set system clock to 270MHz
    stdio_init_all();     // Initialize stdio
    setup_gpio();     // Initialize GPIO

    // Multicore setup
    multicore_launch_core1(wireless_main); // Launch core 1
    // Load the ROM data from flash memory
    int rom_index = loadrom_msx_menu(0x0000); //load the first 32KB ROM into the MSX (The MSX PICOVERSE MENU)

    // Load the selected ROM into the MSX according to the mapper
    switch (records[rom_index].Mapper) {
        case 1:
        case 2:
            loadrom_plain32(records[rom_index].Offset);
            break;
        case 3:
            loadrom_konamiscc(records[rom_index].Offset);
            break;
        case 4:
            loadrom_linear48(records[rom_index].Offset);
            break;
        case 5:
            loadrom_ascii8(records[rom_index].Offset); 
            break;
        case 6:
            loadrom_ascii16(records[rom_index].Offset); 
            break;
        case 7:
            loadrom_konami(records[rom_index].Offset); 
            break;
        case 8:
            loadrom_neo8(records[rom_index].Offset); 
            break;
        case 9:
            loadrom_neo16(records[rom_index].Offset); 
            break;
        default:
            printf("Debug: Unsupported ROM mapper: %d\n", records[rom_index].Mapper);
            break;
    }
    
}

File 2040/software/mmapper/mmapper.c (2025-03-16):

// MSX PICOVERSE PROJECT
// (c) 2024 Cristiano Goncalves
// The Retro Hacker
//
// mmapper.c - This is a memory mapper implementation for the MSX
//
// This program implements a simple memory mapper for the MSX computer using the Raspberry Pi Pico.
//
// This work is licensed  under a "Creative Commons Attribution-NonCommercial-ShareAlike 4.0 International
// License". https://creativecommons.org/licenses/by-nc-sa/4.0/

#include <stdio.h>
#include <string.h>
#include "pico/stdlib.h"
#include "hardware/clocks.h"

// -----------------------
// User-defined pin assignments
// -----------------------
// Address lines (A0-A15) as inputs from MSX
#define PIN_A0     0 
#define PIN_A1     1
#define PIN_A2     2
#define PIN_A3     3
#define PIN_A4     4
#define PIN_A5     5
#define PIN_A6     6
#define PIN_A7     7
#define PIN_A8     8
#define PIN_A9     9
#define PIN_A10    10
#define PIN_A11    11
#define PIN_A12    12
#define PIN_A13    13
#define PIN_A14    14
#define PIN_A15    15

// Data lines (D0-D7)
#define PIN_D0     16
#define PIN_D1     17
#define PIN_D2     18
#define PIN_D3     19
#define PIN_D4     20
#define PIN_D5     21
#define PIN_D6     22
#define PIN_D7     23

// Control signals
#define PIN_RD     24   // Read strobe from MSX
#define PIN_WR     25   // Write strobe from MSX
#define PIN_IORQ   26   // IO Request line from MSX
#define PIN_SLTSL  27   // Slot Select for this cartridge slot
#define PIN_WAIT    28  // WAIT line to MSX 
#define PIN_BUSSDIR 29  // Bus direction line to MSX


// Initialize GPIO pins
static inline void setup_gpio()
{
    // address pins
    gpio_init(PIN_A0);  gpio_set_dir(PIN_A0, GPIO_IN);
    gpio_init(PIN_A1);  gpio_set_dir(PIN_A1, GPIO_IN);
    gpio_init(PIN_A2);  gpio_set_dir(PIN_A2, GPIO_IN);
    gpio_init(PIN_A3);  gpio_set_dir(PIN_A3, GPIO_IN);
    gpio_init(PIN_A4);  gpio_set_dir(PIN_A4, GPIO_IN);
    gpio_init(PIN_A5);  gpio_set_dir(PIN_A5, GPIO_IN);
    gpio_init(PIN_A6);  gpio_set_dir(PIN_A6, GPIO_IN);
    gpio_init(PIN_A7);  gpio_set_dir(PIN_A7, GPIO_IN);
    gpio_init(PIN_A8);  gpio_set_dir(PIN_A8, GPIO_IN);
    gpio_init(PIN_A9);  gpio_set_dir(PIN_A9, GPIO_IN);
    gpio_init(PIN_A10); gpio_set_dir(PIN_A10, GPIO_IN);
    gpio_init(PIN_A11); gpio_set_dir(PIN_A11, GPIO_IN);
    gpio_init(PIN_A12); gpio_set_dir(PIN_A12, GPIO_IN);
    gpio_init(PIN_A13); gpio_set_dir(PIN_A13, GPIO_IN);
    gpio_init(PIN_A14); gpio_set_dir(PIN_A14, GPIO_IN);
    gpio_init(PIN_A15); gpio_set_dir(PIN_A15, GPIO_IN);

    // data pins
    gpio_init(PIN_D0); 
    gpio_init(PIN_D1); 
    gpio_init(PIN_D2); 
    gpio_init(PIN_D3); 
    gpio_init(PIN_D4); 
    gpio_init(PIN_D5); 
    gpio_init(PIN_D6);  
    gpio_init(PIN_D7); 

    // Initialize control pins as input
    gpio_init(PIN_RD); gpio_set_dir(PIN_RD, GPIO_IN);
    gpio_init(PIN_WR); gpio_set_dir(PIN_WR, GPIO_IN);
    gpio_init(PIN_IORQ); gpio_set_dir(PIN_IORQ, GPIO_IN);
    gpio_init(PIN_SLTSL); gpio_set_dir(PIN_SLTSL, GPIO_IN);
    gpio_init(PIN_BUSSDIR); gpio_set_dir(PIN_BUSSDIR, GPIO_IN);
}


void __no_inline_not_in_flash_func(msxmmapper)(void)
{
    static uint8_t sram_data[128 * 1024];        // 128KB of RAM in the Pico to be “mapped” in 16KB banks
    memset(sram_data, 0x00, sizeof(sram_data));  // Clear the SRAM

    static uint8_t pageRegister[4] = {0, 1, 2, 3};     // Four page registers for 4 pages of 16KB each

    while (true)
    {
        bool sltsl = !(gpio_get(PIN_SLTSL));  // Cartridge slot select
        bool iorq  = !(gpio_get(PIN_IORQ));   // I/O request
        bool rd    = !(gpio_get(PIN_RD));     // Read strobe
        bool wr    = !(gpio_get(PIN_WR));     // Write strobe
        
        if (!sltsl) {
            // Full 16-bit address (A0..A15)
            uint32_t addr_bus = gpio_get_all() & 0xFFFF;  
            // For an I/O operation, typically the low 8 bits are the port number.
            uint8_t  port = (uint8_t)(addr_bus & 0xFF);
            
            if (iorq)
            {
                if (wr && (port >= 0xFC && port <= 0xFF))
                {
                    gpio_set_dir_in_masked(0xFF << 16);   // Set data bus to input mode
                    uint8_t data = (gpio_get_all() >> 16) & 0xFF;  // Get the written value on D0..D7
                    uint8_t page = port - 0xFC;           // Which page register? port 0xFC => page 0, 0xFD => page 1, etc.
                    pageRegister[page] = data & 0x07;     // Only 8 banks in 128KB
                    while (!(gpio_get(PIN_WR))) {         // Wait for WR to go high again (to complete the bus cycle)

                        tight_loop_contents();
                    }
                } else if (rd && (port >= 0xFC && port <= 0xFF))
                {
                    gpio_set_dir_out_masked(0xFF << 16); // Set data bus to output mode
                    uint8_t page = port - 0xFC;
                    uint8_t data = pageRegister[page];
                    gpio_put_masked(0xFF0000, data << 16); // Write the data to the data bus
                    while (!(gpio_get(PIN_RD))) {                 // Wait for RD to go high again

                        tight_loop_contents();
                    }
                    gpio_set_dir_in_masked(0xFF << 16); // Set data bus to input mode
                }
            }
            else
            {
                uint8_t page = (addr_bus >> 14) & 0x03;  // top 2 bits
                uint8_t bank = pageRegister[page];       // which 16KB block for this page

                // offset within that bank
                uint16_t offset_in_bank = addr_bus & 0x3FFF;
                // global offset = bank * 16KB + offset_in_bank
                uint32_t sram_offset = (bank * 0x4000) + offset_in_bank;
                if (rd)
                {
                    gpio_set_dir_out_masked(0xFF << 16); // Set data bus to output mode
                    uint8_t data = sram_data[sram_offset];  // Read from our local 128KB array
                    gpio_put_masked(0xFF0000, data << 16); // Write the data to the data bus
                    while (!(gpio_get(PIN_RD))) {     // Wait for RD to go high

                        tight_loop_contents();
                    }
                    gpio_set_dir_in_masked(0xFF << 16); // Set data bus to input mode
                }
                else if (wr)
                {
                    gpio_set_dir_in_masked(0xFF << 16); // Set data bus to input mode
                    uint8_t data = (gpio_get_all() >> 16) & 0xFF;  // Read the byte being written
                    sram_data[sram_offset] = data;   // Store into our local 128KB array
                    while (!(gpio_get(PIN_WR))) {  // Wait for WR to go high
                        tight_loop_contents();
                    }
                }
            }
        }
    }

}

int main()
{
    set_sys_clock_khz(270000, true);
    // Initialize stdio
    stdio_init_all();
    // Initialize GPIO
    setup_gpio();
    msxmmapper();
}

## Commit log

2025-03-16 Nextor driver is READY!
2025-03-16 updating documentation + file reorg
    [bom.csv, designators.csv, msx-picoverse.kicad_pcb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]
2025-03-16 microSD card slot circuit update for 2350
    [msx-picoverse.kicad_sch]
2025-03-17 WiFi implementation for the 2040
    [msx-picoverse.kicad_sch]
2025-03-17 ESP8266 on 2040
    [msx-picoverse.kicad_sch]
